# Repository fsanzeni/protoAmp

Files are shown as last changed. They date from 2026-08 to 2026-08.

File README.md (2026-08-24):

# 100W USB-C PD Audio Amplifier with Integrated DSP

This repository contains the hardware design files, documentation, and firmware logic for a 100W audio amplifier board. The system integrates USB-C Power Delivery (PD) for power management, a dedicated digital signal processor (DSP) for audio manipulation, a Bluetooth Low Energy (BLE) microcontroller for system management, and a high-efficiency Class-D amplification stage.

This platform is designed for active speaker systems, custom crossover networks, and integrated audio processing applications requiring a compact footprint and standardised power inputs.

| PCB Front | PCB Back |
|---|---|
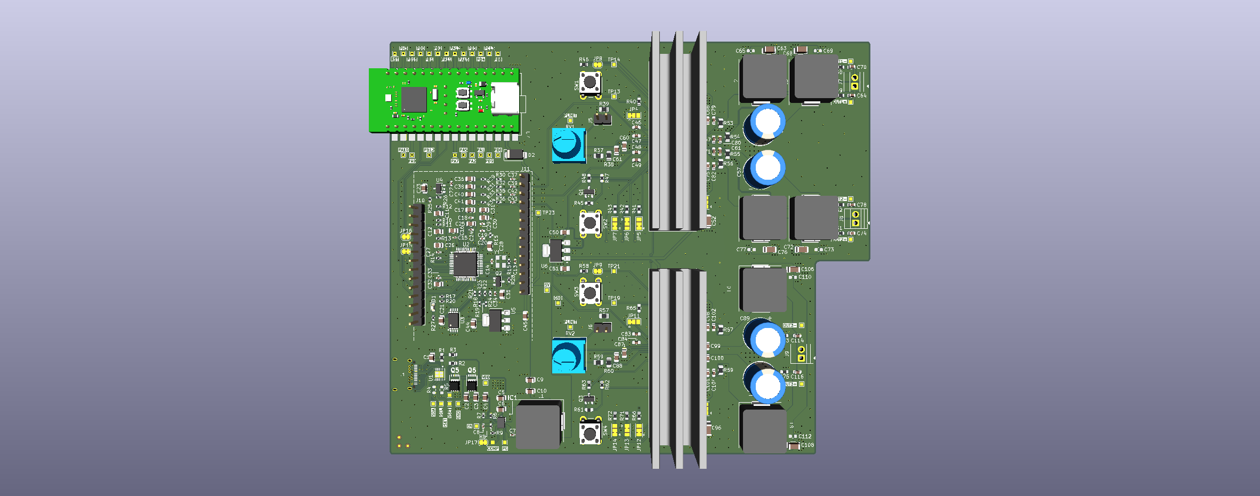
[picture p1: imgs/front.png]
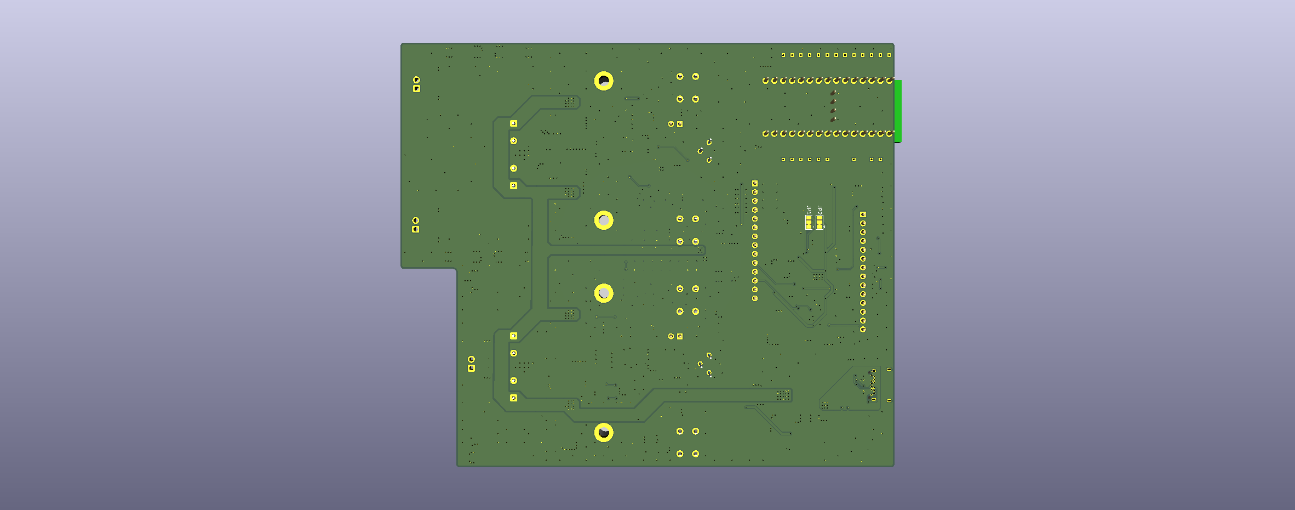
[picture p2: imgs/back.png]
|  |  |

---

## System Architecture and Major Components

The board design relies on a specialised set of integrated circuits to handle power negotiation, wireless connectivity, digital signal processing, and audio amplification.

### USB Power Delivery: HUSB238

The [HUSB238](https://en.hynetek.com/2421.html) serves as the USB Type-C PD sink controller. It handles the low-level negotiation with the connected USB-C power source to request the necessary voltage and current (up to 20V at 5A, yielding 100W).

* **Protocol:** Compliant with USB PD 3.0 and Type-C 1.4 specifications.
* **Interface:** Interfaced via I2C, allowing the system MCU to read negotiated power capabilities and dynamically limit the amplifier's maximum output power to prevent source overcurrent.
* **Functionality:** Operates independently of the MCU for fundamental power requests, ensuring rapid voltage ramp-up and system stability upon cable insertion. Please note: without writing some code and pushing it via the exposed I2C lines, the HUSB238 can only output a maximum of 20V @ 3A (60W). This is a safety feature. Please see e.g., [Adafruit's](https://github.com/adafruit/Adafruit_HUSB238) code to figure out how to request up to 100W.

### Digital Signal Processor: ADAU1701

Audio processing is handled by the Analog Devices [ADAU1701](https://www.analog.com/en/products/adau1701.html), a fully programmable 28-/56-bit audio DSP.

* **Processing:** Executes audio algorithms at a high sample rate, suitable for bi-quad filters, dynamic range compression, time alignment, and active crossovers.
* **I/O Routing:** Features two built-in ADCs and four DACs, allowing for stereo input and up to four channels of analog output (e.g., routing separate high-frequency and low-frequency channels to the amplification stage).
* **Programming:** Configurable via Analog Devices' SigmaStudio. The DSP boots from an external EEPROM or is initialised via the I2C bus by the system MCU.

### System Controller & Wireless: STM32WBA65

The STMicroelectronics [STM32WBA65CIU6](https://www.st.com/en/microcontrollers-microprocessors/stm32wba65ci.html) acts as the central brain of the board. It is an ultra-low-power Arm Cortex-M33 microcontroller with integrated Bluetooth LE Audio capabilities.

* **System Management:** Acts as the I2C master to configure the HUSB238 (via solder jumpers) and the ADAU1701 (loading DSP parameters or switching presets).
* **Connectivity:** Handles Bluetooth Low Energy (BLE) connections for audio streaming and remote configuration, effectively acting as the bridge between mobile applications and the onboard DSP.

### Audio Amplification Stage

The output stage uses a Class-D amplifier topology configured to deliver up to 100W of total output power, distributed as either a bridged mono (PBTL) output or a standard stereo configuration - or a combination of both.

I'm using here a pair of synced [TPA3126D2DADR](https://www.ti.com/product/TPA3126D2/part-details/TPA3126D2DADR) - one configured as a 50-W stereo amp, the second as a 100-W amp. Obviously you can't request their max wattage at the same time, so I've included a PLIMIT circuit for both. You can also limit the individual amp's power limits via the DSP / SigmaStudio, but better safe than sorry!

---

## License

This project is licensed under the MIT License.

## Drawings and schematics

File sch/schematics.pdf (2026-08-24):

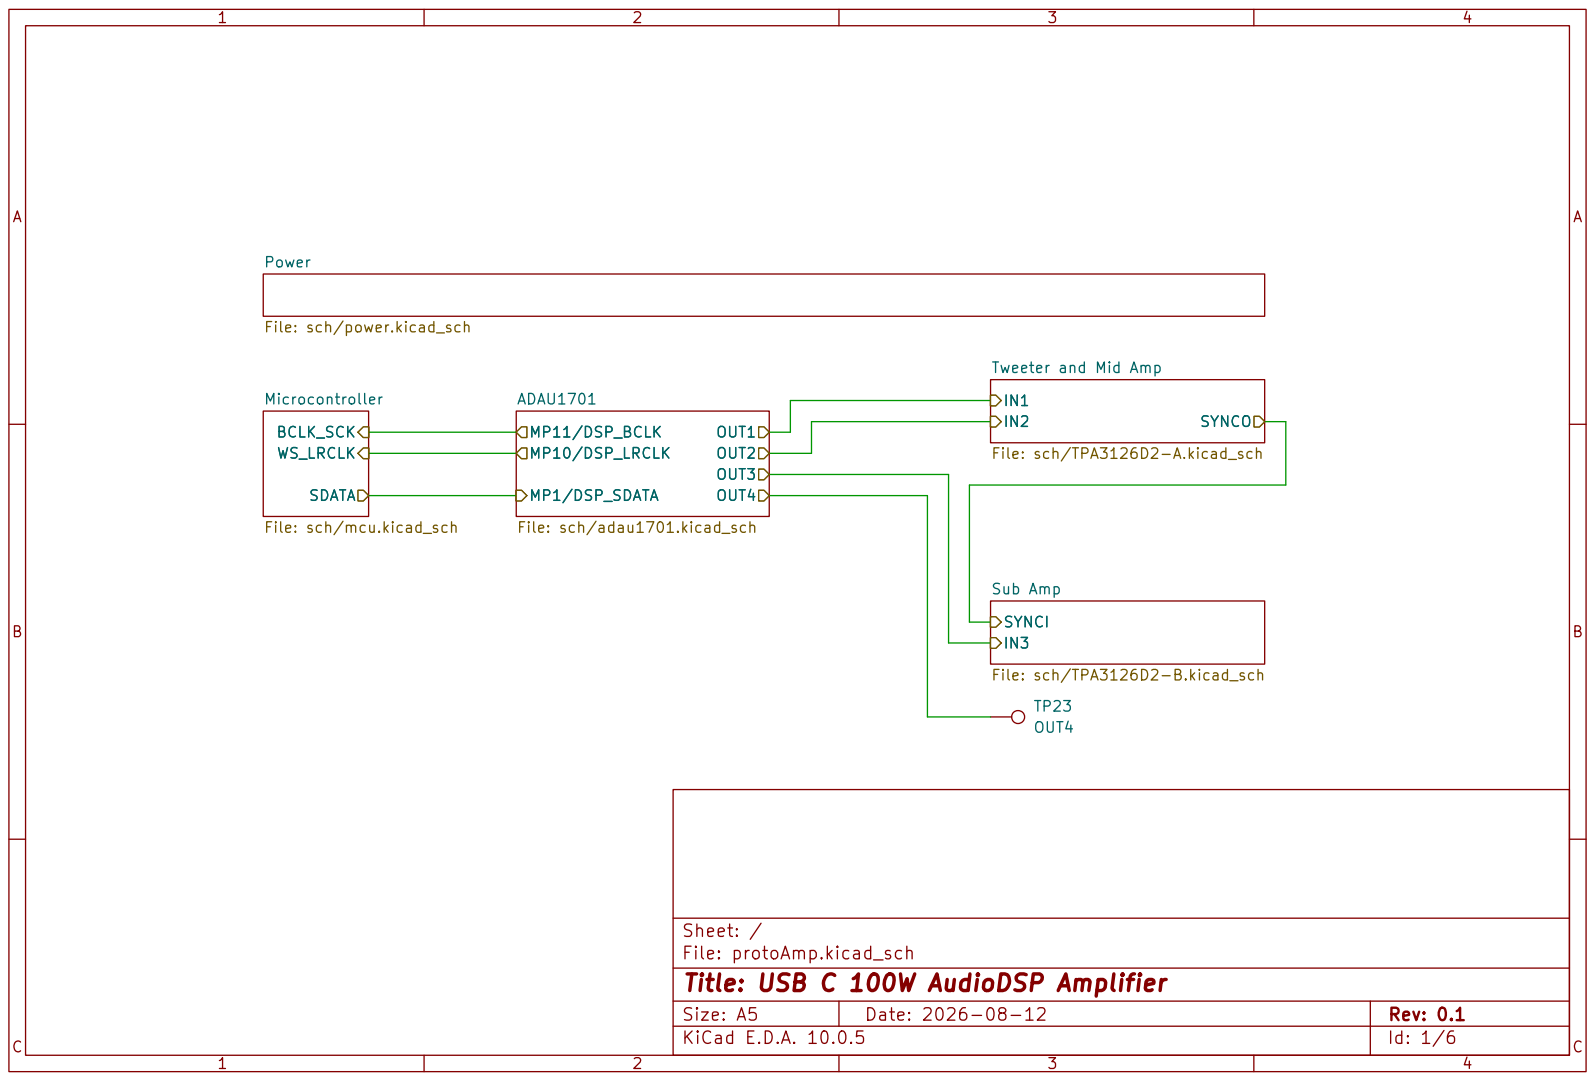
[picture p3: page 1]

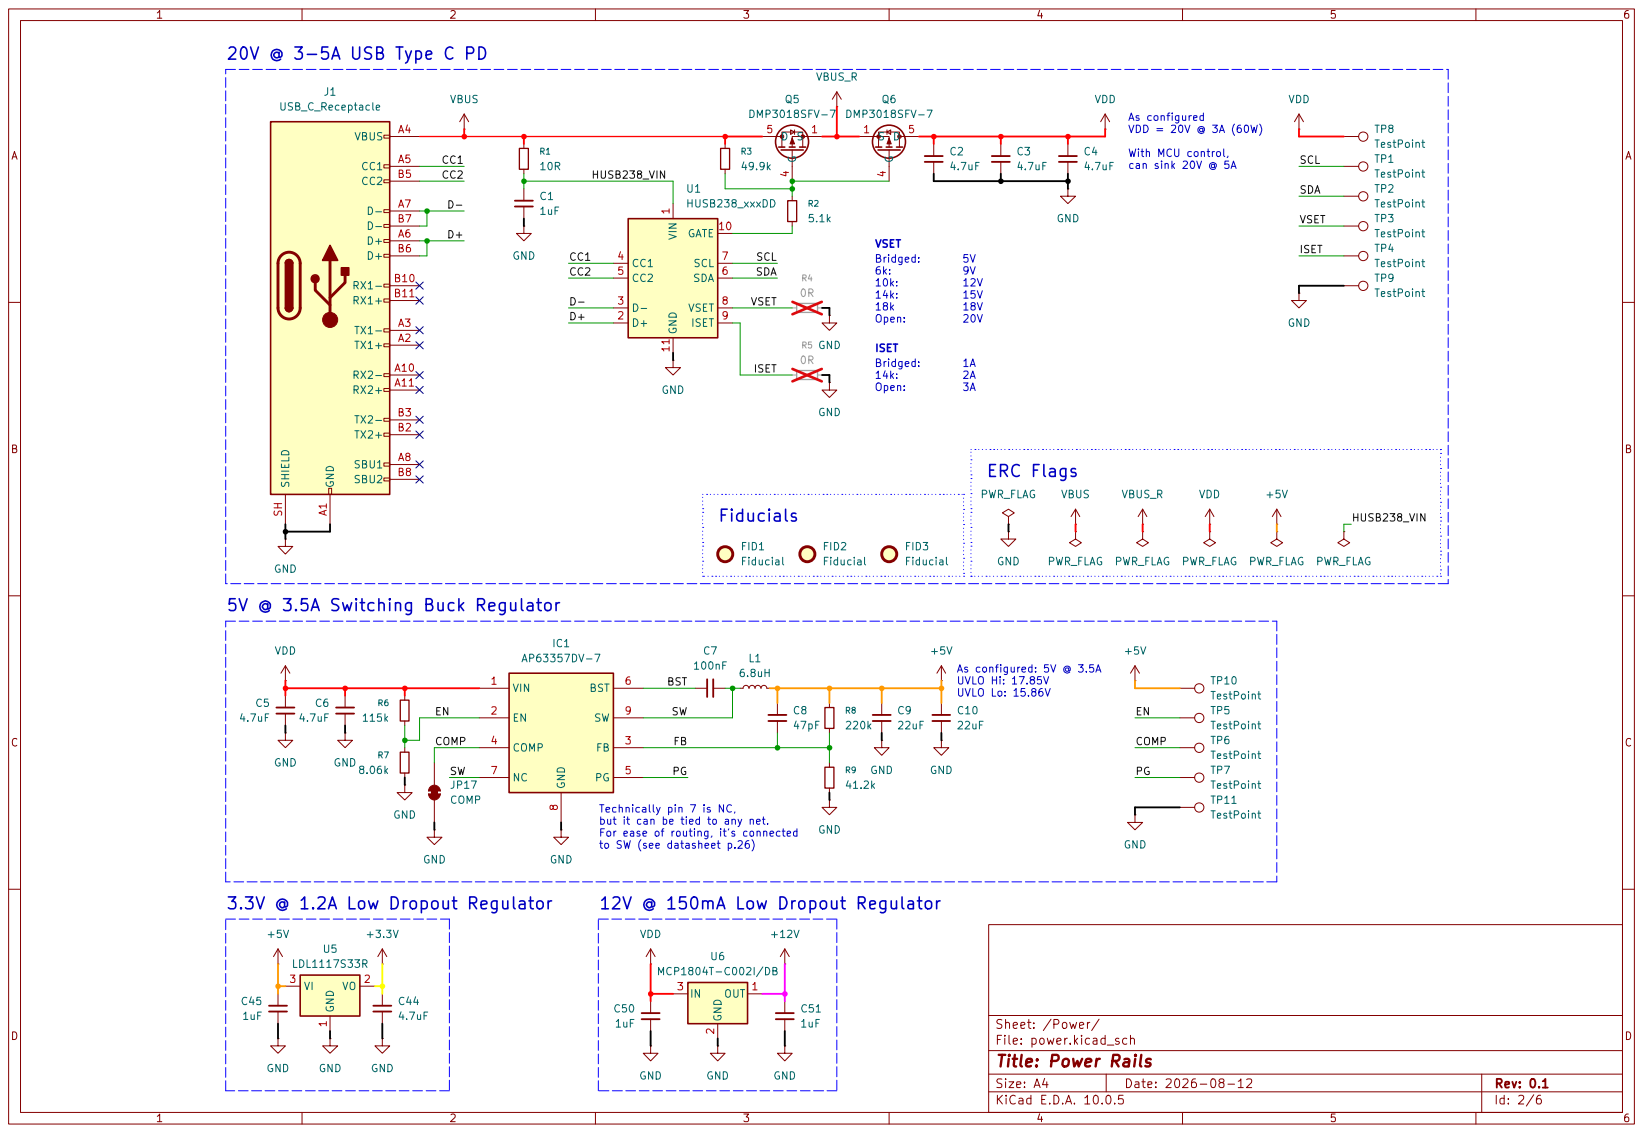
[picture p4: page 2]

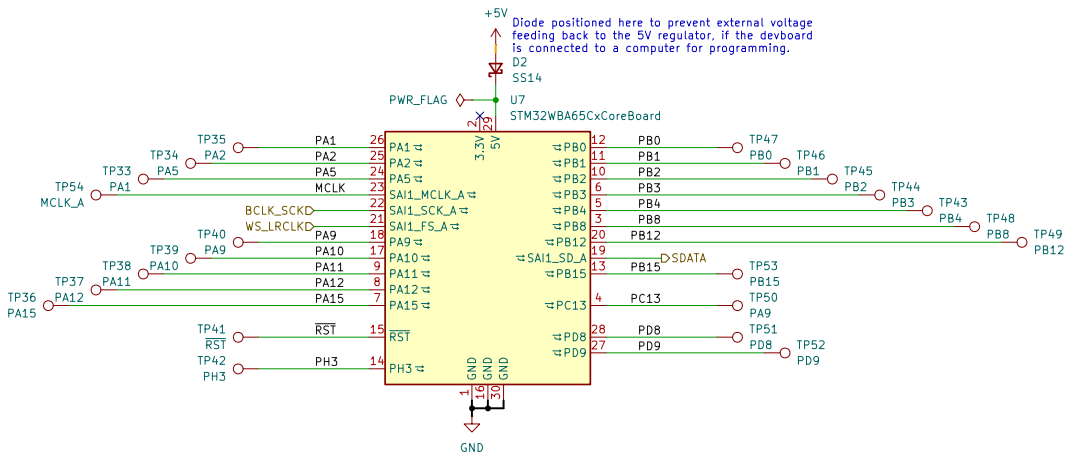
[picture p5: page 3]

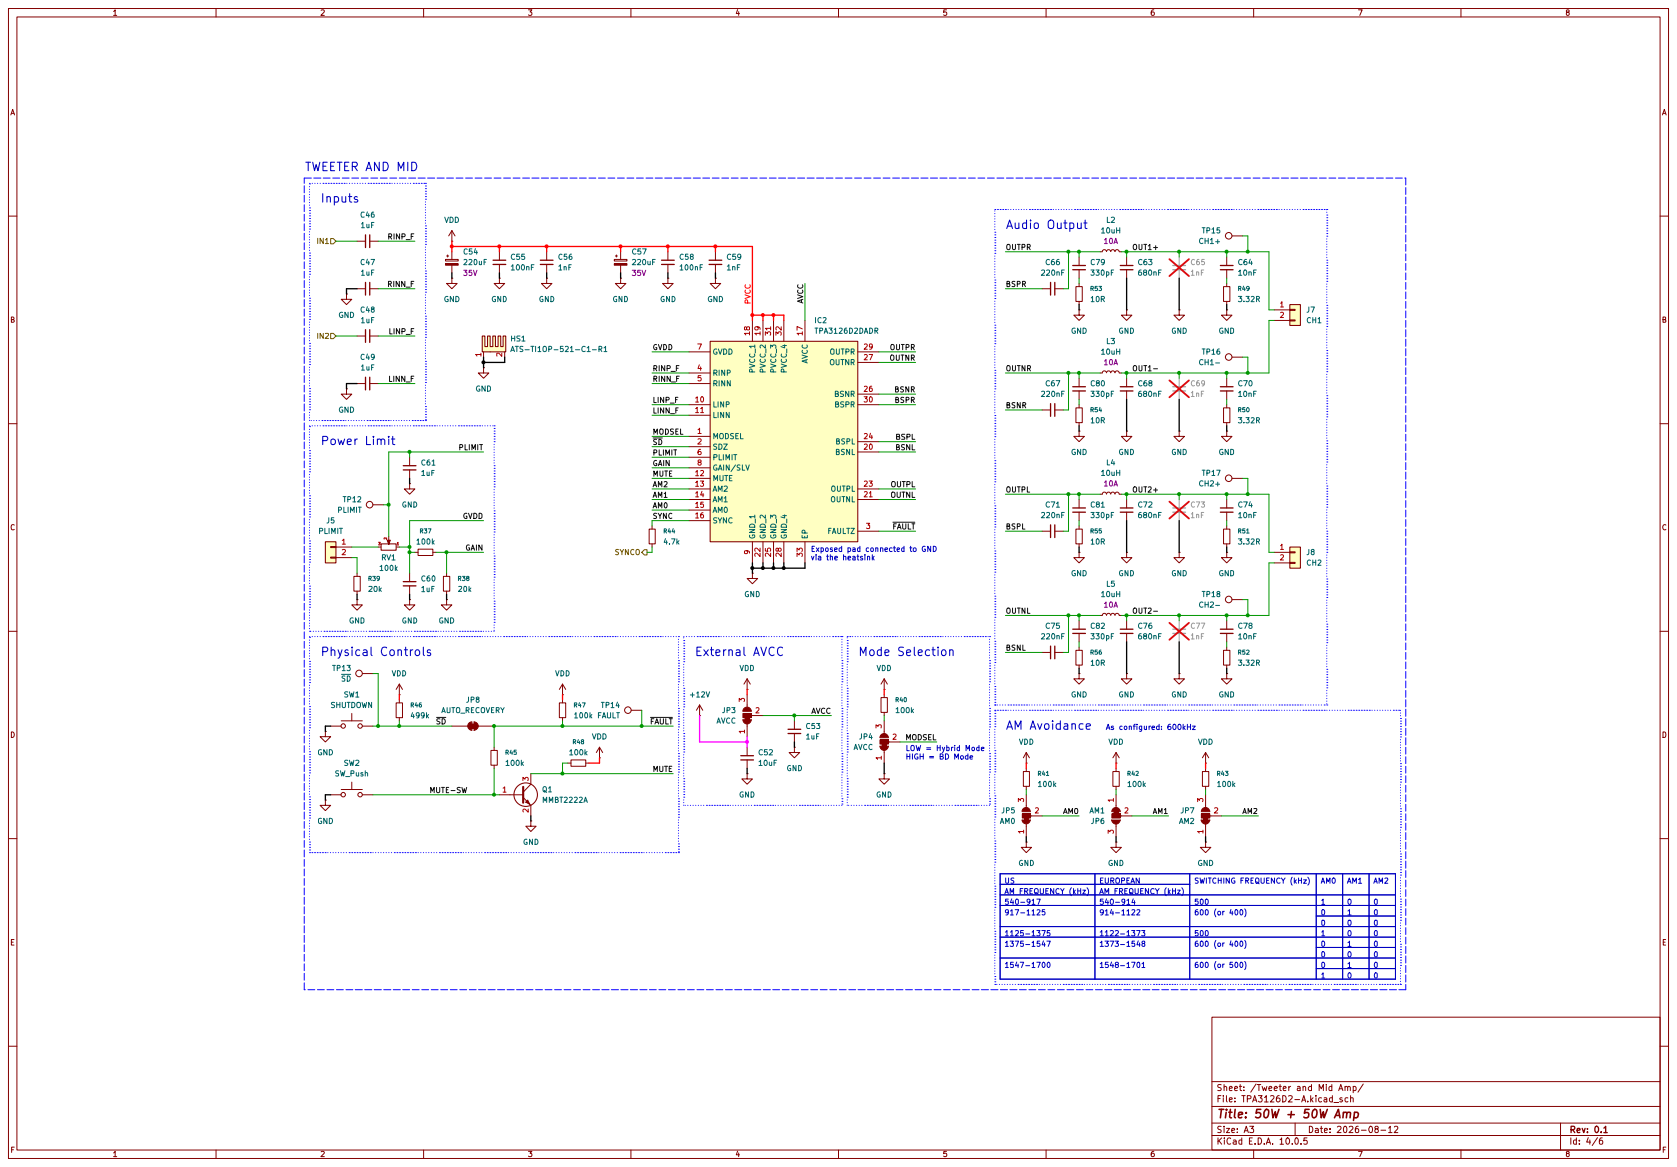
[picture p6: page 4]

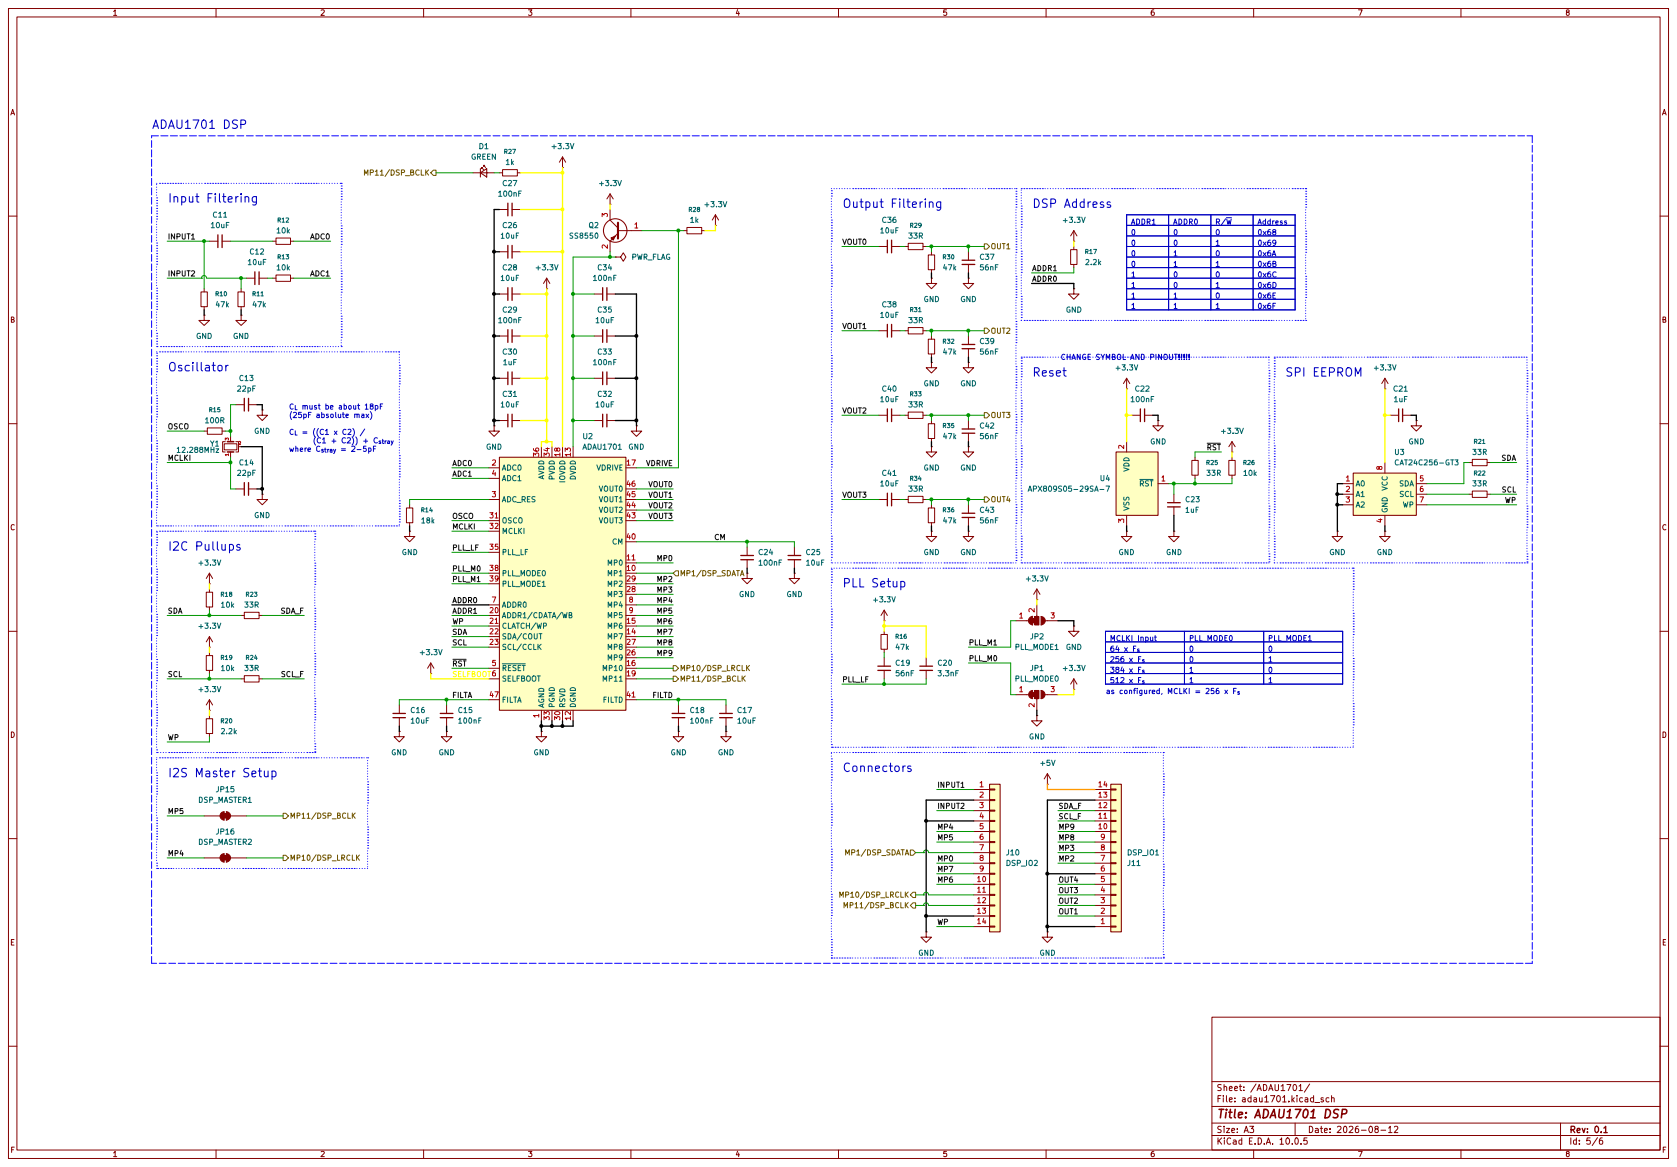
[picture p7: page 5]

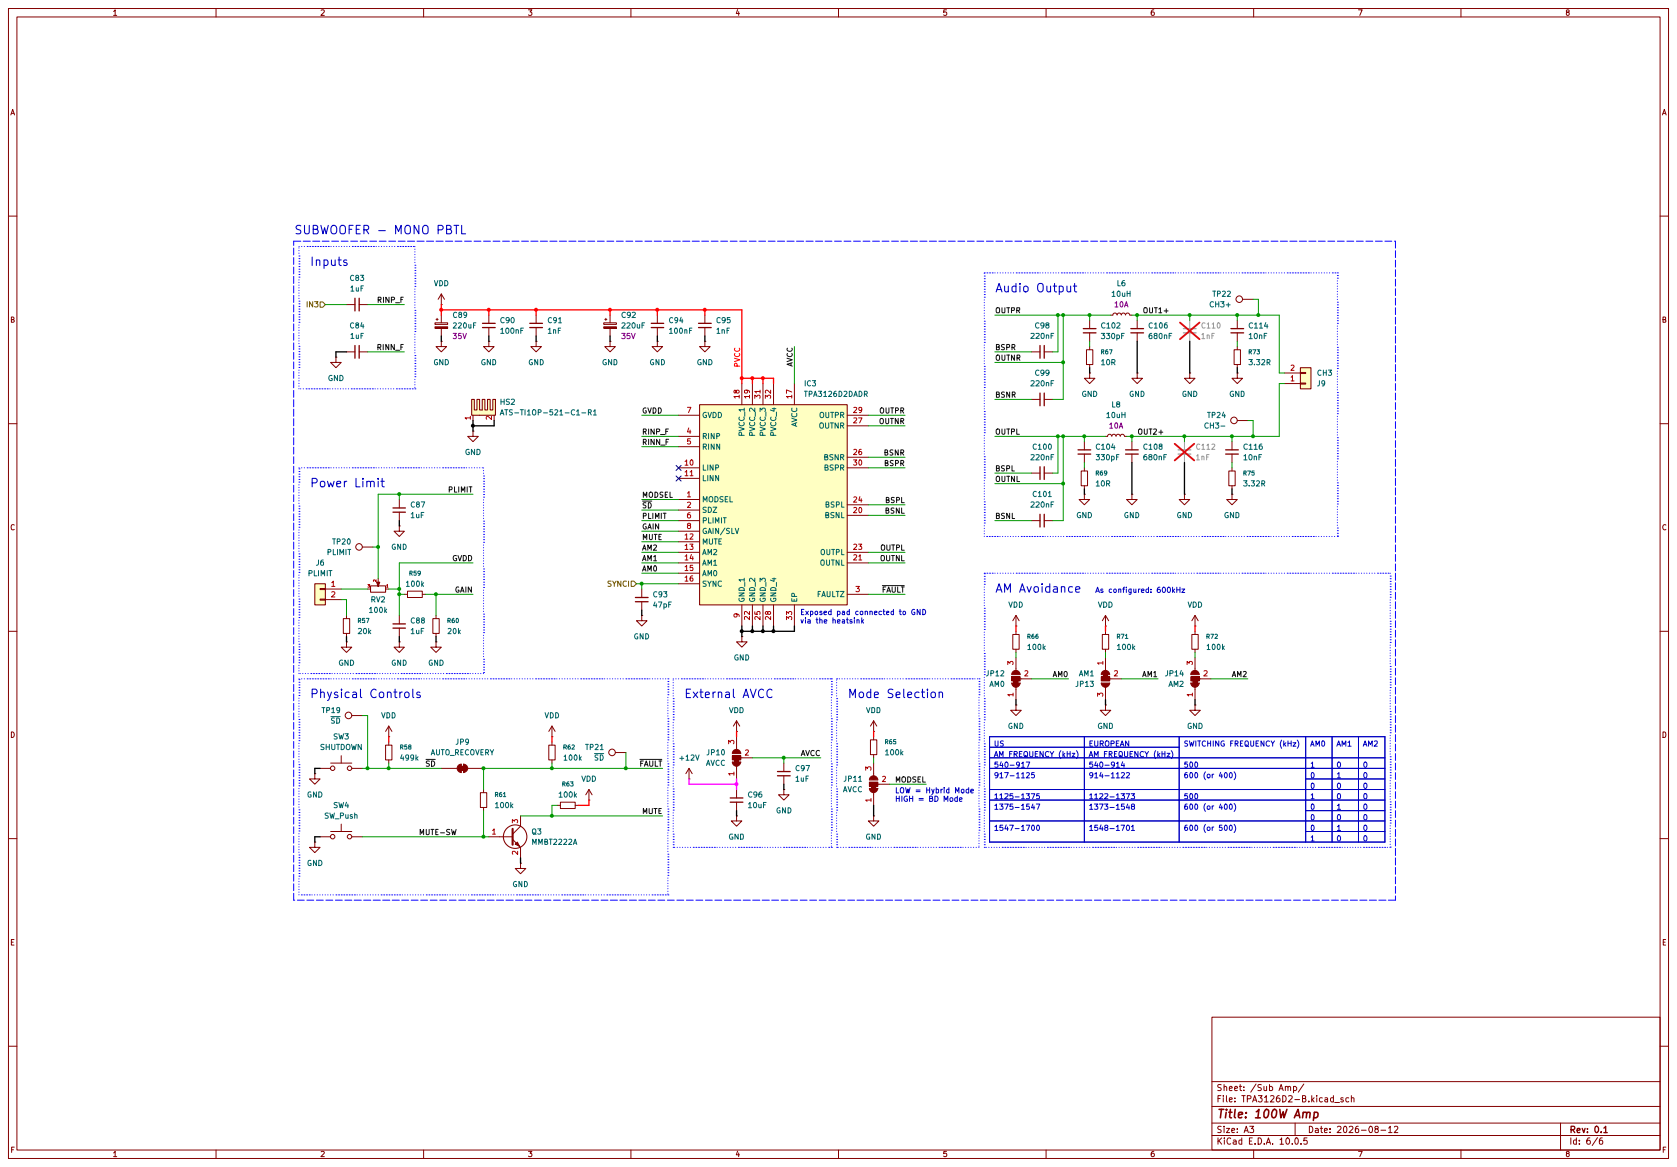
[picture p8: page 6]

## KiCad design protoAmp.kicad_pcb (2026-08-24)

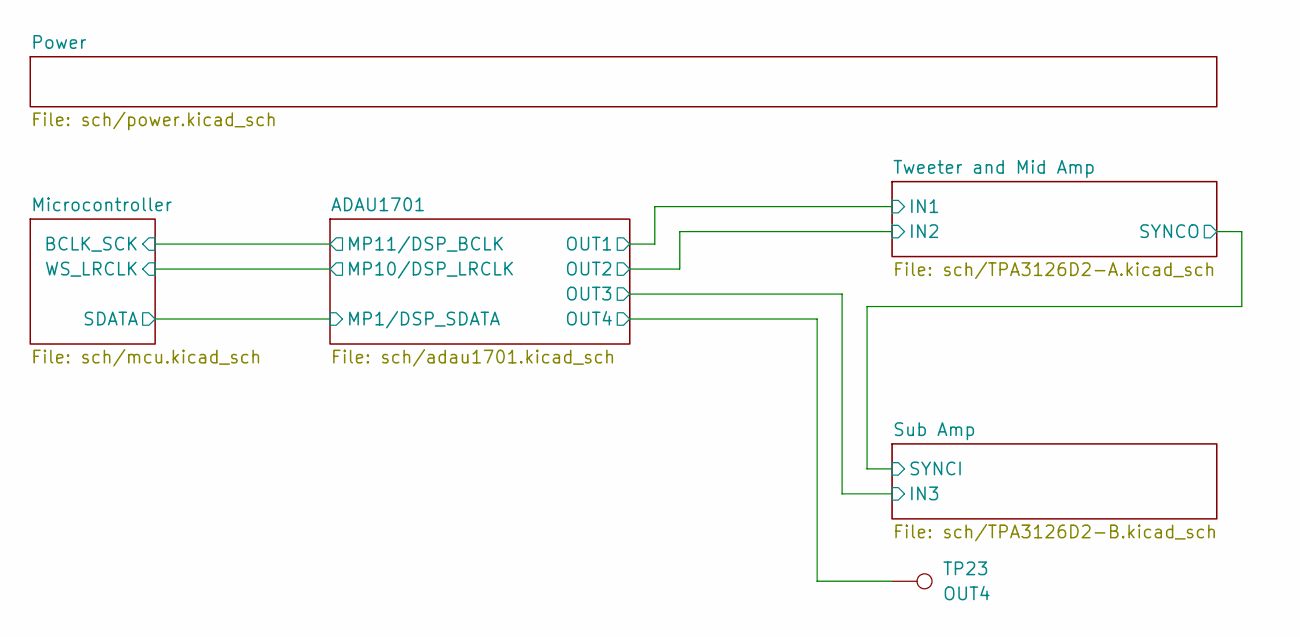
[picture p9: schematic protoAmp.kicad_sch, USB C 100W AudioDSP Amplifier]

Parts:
TP23: OUT4; TestPoint_Pad_1.0x1.0mm

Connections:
/ADAU1701/OUT4: TP23.1 (1_1); also elsewhere on the board

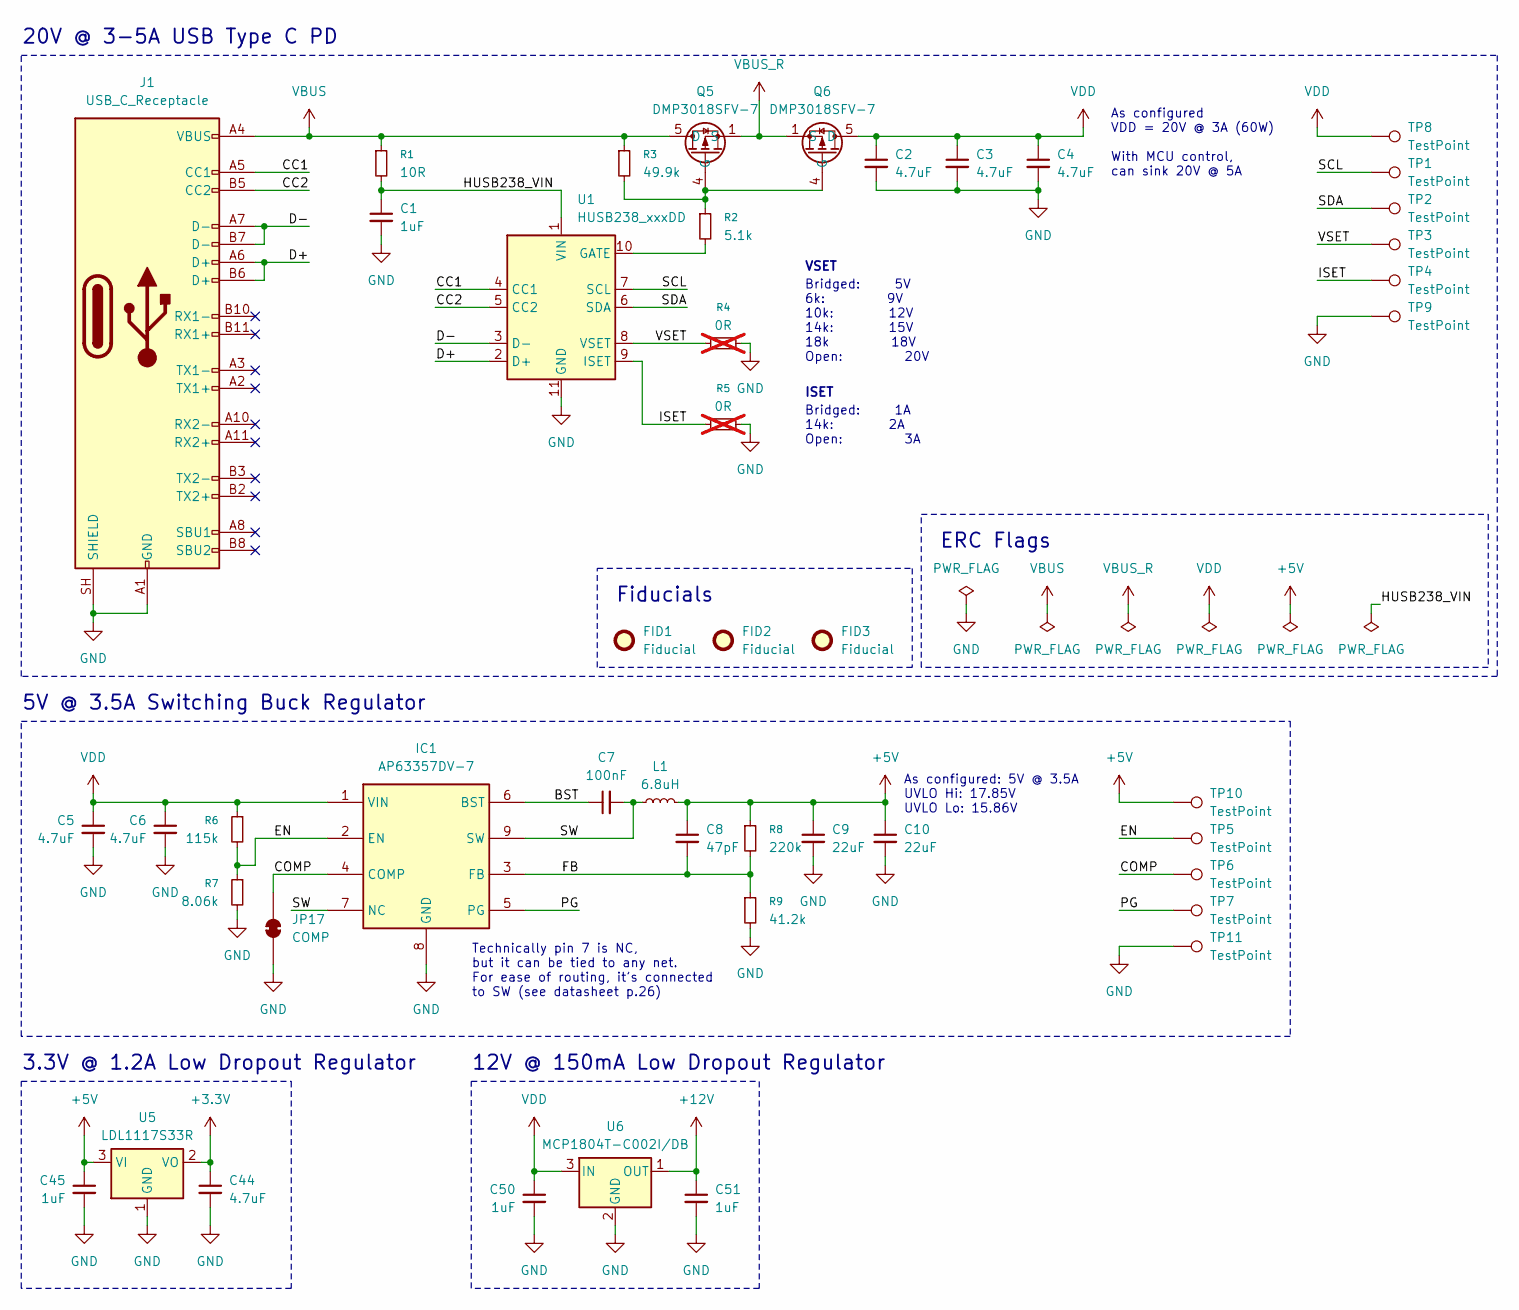
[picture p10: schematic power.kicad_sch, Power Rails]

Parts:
C1, C45, C50, C51: 1uF; C_0805_2012Metric
C2, C3, C4, C5, C6, C44: 4.7uF; C_0805_2012Metric
C7: 100nF; C_0402_1005Metric
C8: 47pF; C_0402_1005Metric
C9, C10: 22uF; C_0805_2012Metric
FID1, FID2, FID3: Fiducial; Fiducial_0.75mm_Mask1.5mm
IC1: AP63357DV-7; AP63357DV7; Mouser Part Number 621-AP63357DV-7
J1: USB_C_Receptacle; USB4900-00-A
JP17: COMP; SolderJumper-2_P1.3mm_Bridged_RoundedPad1.0x1.5mm
L1: 6.8uH; SRP1265A-100M
Q5, Q6: DMP3018SFV-7; DMP3036SFV7; Mouser Part Number 621-DMP3018SFV-7
R1: 10R; R_0603_1608Metric
R2: 5.1k; R_0603_1608Metric
R3: 49.9k; R_0603_1608Metric
R4, R5: 0R; R_0603_1608Metric; not fitted
R6: 115k; R_0402_1005Metric
R7: 8.06k; R_0402_1005Metric
R8: 220k; R_0402_1005Metric
R9: 41.2k; R_0402_1005Metric
TP1, TP2, TP3, TP4, TP5, TP6, TP7, TP8, TP9, TP10, TP11: TestPoint; TestPoint_Pad_1.0x1.0mm
U1: HUSB238_xxxDD; WDFN-10-1EP_3x3mm_P0.5mm_EP1.8x2.5mm
U5: LDL1117S33R; SOT-223-3_TabPin2
U6: MCP1804T-C002I/DB; SOT-223-3_TabPin2

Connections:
+3.3V: C44.1, U5.2 (VO); also elsewhere on the board
+5V: C8.1, C9.1, C10.1, C45.1, L1.2, R8.1, TP10.1 (1_1), U5.3 (VI); also elsewhere on the board
+12V: C51.1, U6.1 (OUT); also elsewhere on the board
/Power/BST: C7.1, IC1.6 (BST)
/Power/CC1: J1.A5 (CC1), U1.4 (CC1)
/Power/CC2: J1.B5 (CC2), U1.5 (CC2)
/Power/COMP: IC1.4 (COMP), JP17.1 (A), TP6.1 (1_1)
/Power/D+: J1.A6 (D+), J1.B6 (D+), U1.2 (D+)
/Power/D-: J1.A7 (D-), J1.B7 (D-), U1.3 (D-)
/Power/EN: IC1.2 (EN), R6.2, R7.1, TP5.1 (1_1)
/Power/FB: C8.2, IC1.3 (FB), R8.2, R9.1
/Power/HUSB238_VIN: C1.1, R1.2, U1.1 (VIN)
/Power/ISET: R5.1, TP4.1 (1_1), U1.9 (ISET)
/Power/PG: IC1.5 (PG), TP7.1 (1_1)
/Power/SCL: TP1.1 (1_1), U1.7 (SCL)
/Power/SDA: TP2.1 (1_1), U1.6 (SDA)
/Power/SW: C7.2, IC1.7 (NC), IC1.9 (SW), L1.1
/Power/VSET: R4.1, TP3.1 (1_1), U1.8 (VSET)
GND: C1.2, C2.2, C3.2, C4.2, C5.2, C6.2, C9.2, C10.2, C44.2, C45.2, C50.2, C51.2, IC1.8 (GND), J1.A1 (GND), J1.A12 (GND), J1.B1 (GND), J1.B12 (GND), J1.SH (SHIELD), JP17.2 (B), R4.2, R5.2, R7.2, R9.2, TP9.1 (1_1), TP11.1 (1_1), U1.11 (GND), U5.1 (GND), U6.2 (GND); also elsewhere on the board
unnamed: Q5.4 (G), Q6.4 (G), R2.1, R3.2
unnamed: R2.2, U1.10 (GATE)
VBUS: J1.A4 (VBUS), J1.A9 (VBUS), J1.B4 (VBUS), J1.B9 (VBUS), Q5.5 (D), Q5.6 (D), Q5.7 (D), Q5.8 (D), Q5.9 (D), R1.1, R3.1
VBUS_R: Q5.1 (S), Q5.2 (S), Q5.3 (S), Q6.1 (S), Q6.2 (S), Q6.3 (S)
VDD: C2.1, C3.1, C4.1, C5.1, C6.1, C50.1, IC1.1 (VIN), Q6.5 (D), Q6.6 (D), Q6.7 (D), Q6.8 (D), Q6.9 (D), R6.1, TP8.1 (1_1), U6.3 (IN); also elsewhere on the board

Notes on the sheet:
3.3V @ 1.2A Low Dropout Regulator
Bridged: 1A 14k: 2A Open: 3A
As configured: 5V @ 3.5A UVLO Hi: 17.85V UVLO Lo: 15.86V
Technically pin 7 is NC, but it can be tied to any net. For ease of routing, it's connected to SW (see datasheet p.26)
20V @ 3-5A USB Type C PD
As configured VDD = 20V @ 3A (60W) With MCU control, can sink 20V @ 5A
Fiducials
5V @ 3.5A Switching Buck Regulator
12V @ 150mA Low Dropout Regulator
VSET
Bridged: 5V 6k: 9V 10k: 12V 14k: 15V 18k 18V Open: 20V
ERC Flags
ISET

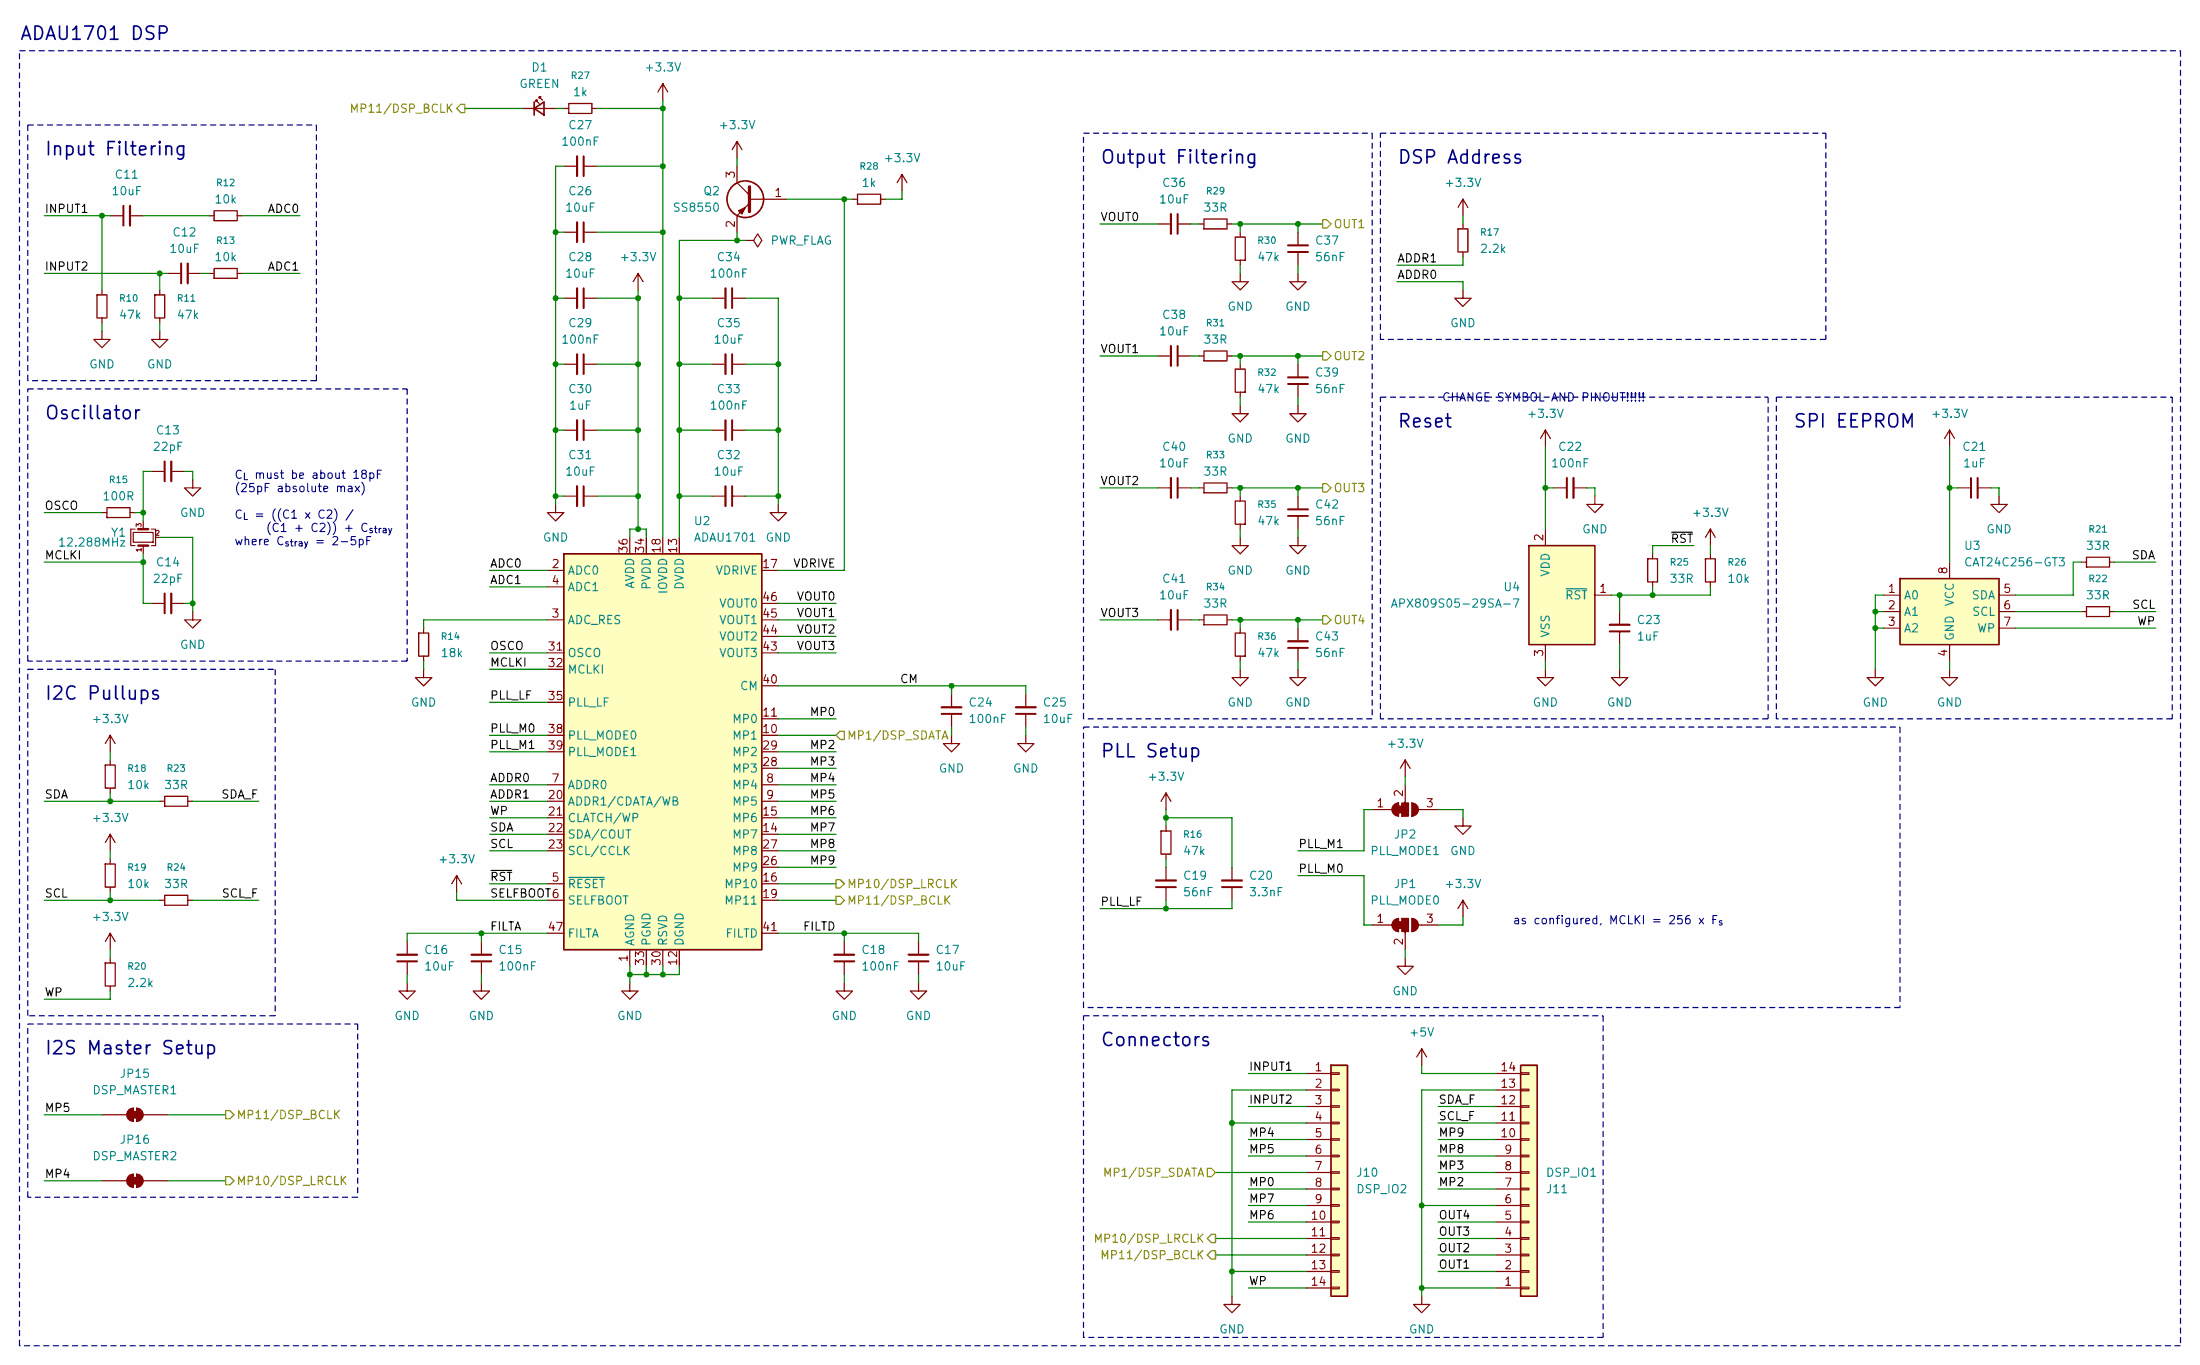
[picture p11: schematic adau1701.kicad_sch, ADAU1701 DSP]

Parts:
C11, C12, C16, C17, C25, C26, C28, C31, C32, C35, C36, C38, C40, C41: 10uF; C_0805_2012Metric
C13, C14: 22pF; C_0402_1005Metric
C15, C18, C22, C24, C27, C29, C33, C34: 100nF; C_0402_1005Metric
C19, C37, C39, C42, C43: 56nF; C_0402_1005Metric
C20: 3.3nF; C_0402_1005Metric
C21, C23, C30: 1uF; C_0805_2012Metric
D1: GREEN; LED_0603_1608Metric
J10: DSP_IO2; PinHeader_1x14_P2.54mm_Vertical
J11: DSP_IO1; PinHeader_1x14_P2.54mm_Vertical
JP1: PLL_MODE0; SolderJumper-3_P1.3mm_Bridged12_Pad1.0x1.5mm
JP2: PLL_MODE1; SolderJumper-3_P1.3mm_Bridged12_Pad1.0x1.5mm
JP15: DSP_MASTER1; SolderJumper-2_P1.3mm_Bridged_RoundedPad1.0x1.5mm
JP16: DSP_MASTER2; SolderJumper-2_P1.3mm_Bridged_RoundedPad1.0x1.5mm
Q2: SS8550; SOT-23
R10, R11, R16, R30, R32, R35, R36: 47k; R_0402_1005Metric
R12, R13, R18, R19, R26: 10k; R_0402_1005Metric
R14: 18k; R_0402_1005Metric
R15: 100R; R_0402_1005Metric
R17, R20: 2.2k; R_0402_1005Metric
R21, R22, R23, R24, R25, R29, R31, R33, R34: 33R; R_0402_1005Metric
R27, R28: 1k; R_0402_1005Metric
U2: ADAU1701; LQFP-48_7x7mm_P0.5mm
U3: CAT24C256-GT3; TSSOP-8_4.4x3mm_P0.65mm
U4: APX809S05-29SA-7; SOT-23-3
Y1: 12.288MHz; XTM32012288JT00351001

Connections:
+3.3V: C20.2, C21.1, C22.1, C26.1, C27.1, C28.1, C29.1, C30.1, C31.1, JP1.3 (B), JP2.2 (C), Q2.3 (C), R16.1, R17.1, R18.1, R19.1, R20.1, R26.1, R27.2, R28.2, U2.6 (SELFBOOT), U2.18 (IOVDD), U2.34 (PVDD), U2.36 (AVDD), U2.48 (AVDD), U3.8 (VCC), U4.2 (VDD); also elsewhere on the board
+5V: J11.14; also elsewhere on the board
/ADAU1701/ADC0: R12.2, U2.2 (ADC0)
/ADAU1701/ADC1: R13.2, U2.4 (ADC1)
/ADAU1701/ADDR1: R17.2, U2.20 (ADDR1/CDATA/WB)
/ADAU1701/CM: C24.2, C25.2, U2.40 (CM)
/ADAU1701/FILTA: C15.2, C16.2, U2.47 (FILTA)
/ADAU1701/FILTD: C17.2, C18.2, U2.41 (FILTD)
/ADAU1701/INPUT1: C11.1, J10.1, R10.1
/ADAU1701/INPUT2: C12.1, J10.3, R11.1
/ADAU1701/MCLKI: C14.1, U2.32 (MCLKI), Y1.1
/ADAU1701/MP0: J10.8, U2.11 (MP0)
/ADAU1701/MP1/DSP_SDATA: J10.7, U2.10 (MP1); also elsewhere on the board
/ADAU1701/MP2: J11.7, U2.29 (MP2)
/ADAU1701/MP3: J11.8, U2.28 (MP3)
/ADAU1701/MP4: J10.5, JP16.2 (B), U2.8 (MP4)
/ADAU1701/MP5: J10.6, JP15.2 (B), U2.9 (MP5)
/ADAU1701/MP6: J10.10, U2.15 (MP6)
/ADAU1701/MP7: J10.9, U2.14 (MP7)
/ADAU1701/MP8: J11.9, U2.27 (MP8)
/ADAU1701/MP9: J11.10, U2.26 (MP9)
/ADAU1701/MP10/DSP_LRCLK: J10.11, JP16.1 (A), U2.16 (MP10); also elsewhere on the board
/ADAU1701/MP11/DSP_BCLK: D1.1 (K), J10.12, JP15.1 (A), U2.19 (MP11); also elsewhere on the board
/ADAU1701/OSCO: R15.1, U2.31 (OSCO)
/ADAU1701/OUT1: C37.2, J11.2, R29.2, R30.2; also elsewhere on the board
/ADAU1701/OUT2: C39.2, J11.3, R31.2, R32.2; also elsewhere on the board
/ADAU1701/OUT3: C42.2, J11.4, R33.2, R35.2; also elsewhere on the board
/ADAU1701/OUT4: C43.2, J11.5, R34.2, R36.2; also elsewhere on the board
/ADAU1701/PLL_LF: C19.1, C20.1, U2.35 (PLL_LF)
/ADAU1701/PLL_M0: JP1.1 (A), U2.38 (PLL_MODE0)
/ADAU1701/PLL_M1: JP2.1 (A), U2.39 (PLL_MODE1)
/ADAU1701/SCL: R19.2, R22.2, R24.1, U2.23 (SCL/CCLK)
/ADAU1701/SCL_F: J11.11, R24.2
/ADAU1701/SDA: R18.2, R21.2, R23.1, U2.22 (SDA/COUT)
/ADAU1701/SDA_F: J11.12, R23.2
/ADAU1701/VDRIVE: Q2.1 (B), R28.1, U2.17 (VDRIVE)
/ADAU1701/VOUT0: C36.2, U2.46 (VOUT0)
/ADAU1701/VOUT1: C38.2, U2.45 (VOUT1)
/ADAU1701/VOUT2: C40.2, U2.44 (VOUT2)
/ADAU1701/VOUT3: C41.2, U2.43 (VOUT3)
/ADAU1701/WP: J10.14, R20.2, U2.21 (CLATCH/WP), U3.7 (WP)
/ADAU1701/~RST: R25.1, U2.5 (~RESET)
GND: C13.2, C14.2, C15.1, C16.1, C17.1, C18.1, C21.2, C22.2, C23.1, C24.1, C25.1, C26.2, C27.2, C28.2, C29.2, C30.2, C31.2, C32.1, C33.1, C34.1, C35.1, C37.1, C39.1, C42.1, C43.1, J10.2, J10.4, J10.13, J11.1, J11.6, J11.13, JP1.2 (C), JP2.3 (B), R10.2, R11.2, R14.2, R30.1, R32.1, R35.1, R36.1, U2.1 (AGND), U2.7 (ADDR0), U2.12 (DGND), U2.25 (DGND), U2.30 (RSVD), U2.33 (PGND), U2.37 (AGND), U2.42 (AGND), U3.1 (A0), U3.2 (A1), U3.3 (A2), U3.4 (GND), U4.3 (VSS), Y1.2 (G), Y1.4 (G); also elsewhere on the board
unnamed: C11.2, R12.1
unnamed: C12.2, R13.1
unnamed: C13.1, R15.2, Y1.3
unnamed: C19.2, R16.2
unnamed: C36.1, R29.1
unnamed: C38.1, R31.1
unnamed: C40.1, R33.1
unnamed: C41.1, R34.1
unnamed: D1.2 (A), R27.1
unnamed: C32.2, C33.2, C34.2, C35.2, Q2.2 (E), U2.13 (DVDD), U2.24 (DVDD)
unnamed: R14.1, U2.3 (ADC_RES)
unnamed: R22.1, U3.6 (SCL)
unnamed: R21.1, U3.5 (SDA)
unnamed: C23.2, R25.2, R26.2, U4.1 (~RST)

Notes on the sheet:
Reset
C_{L} must be about 18pF (25pF absolute max) C_{L} = ((C1 x C2) / (C1 + C2)) + C_{stray} where C_{stray} = 2-5pF
Output Filtering
PLL Setup
ADAU1701 DSP
Input Filtering
I2S Master Setup
SPI EEPROM
Oscillator
I2C Pullups
as configured, MCLKI = 256 x F_{s}
DSP Address
CHANGE SYMBOL AND PINOUT!!!!!
Connectors

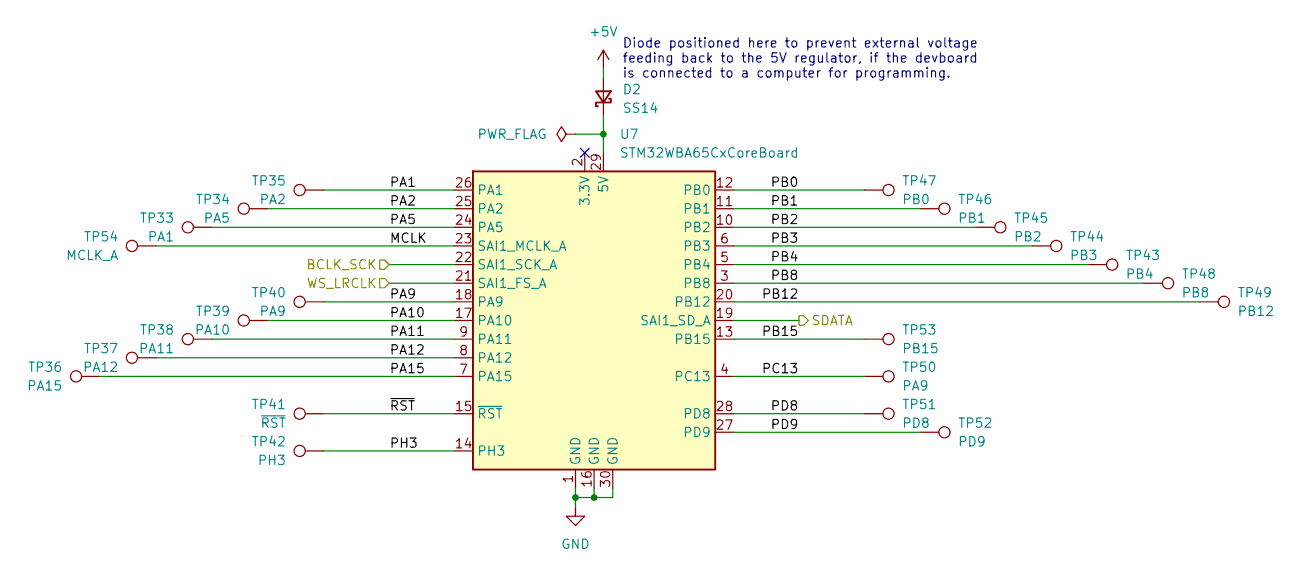
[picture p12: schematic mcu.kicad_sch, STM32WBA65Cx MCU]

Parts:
D2: SS14; D_SMA
TP33: PA1; TestPoint_THTPad_1.0x1.0mm_Drill0.5mm
TP34: PA5; TestPoint_THTPad_1.0x1.0mm_Drill0.5mm
TP35: PA2; TestPoint_THTPad_1.0x1.0mm_Drill0.5mm
TP36: PA15; TestPoint_THTPad_1.0x1.0mm_Drill0.5mm
TP37: PA12; TestPoint_THTPad_1.0x1.0mm_Drill0.5mm
TP38: PA11; TestPoint_THTPad_1.0x1.0mm_Drill0.5mm
TP39: PA10; TestPoint_THTPad_1.0x1.0mm_Drill0.5mm
TP40, TP50: PA9; TestPoint_THTPad_1.0x1.0mm_Drill0.5mm
TP41: ~{RST}; TestPoint_THTPad_1.0x1.0mm_Drill0.5mm
TP42: PH3; TestPoint_THTPad_1.0x1.0mm_Drill0.5mm
TP43: PB4; TestPoint_THTPad_1.0x1.0mm_Drill0.5mm
TP44: PB3; TestPoint_THTPad_1.0x1.0mm_Drill0.5mm
TP45: PB2; TestPoint_THTPad_1.0x1.0mm_Drill0.5mm
TP46: PB1; TestPoint_THTPad_1.0x1.0mm_Drill0.5mm
TP47: PB0; TestPoint_THTPad_1.0x1.0mm_Drill0.5mm
TP48: PB8; TestPoint_THTPad_1.0x1.0mm_Drill0.5mm
TP49: PB12; TestPoint_THTPad_1.0x1.0mm_Drill0.5mm
TP51: PD8; TestPoint_THTPad_1.0x1.0mm_Drill0.5mm
TP52: PD9; TestPoint_THTPad_1.0x1.0mm_Drill0.5mm
TP53: PB15; TestPoint_THTPad_1.0x1.0mm_Drill0.5mm
TP54: MCLK_A; TestPoint_THTPad_1.0x1.0mm_Drill0.5mm
U7: STM32WBA65CxCoreBoard; WeAct STM32WBA65CIU6

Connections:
+5V: D2.2 (A); also elsewhere on the board
/ADAU1701/MP1/DSP_SDATA: U7.19 (SAI1_SD_A); also elsewhere on the board
/ADAU1701/MP10/DSP_LRCLK: U7.21 (SAI1_FS_A); also elsewhere on the board
/ADAU1701/MP11/DSP_BCLK: U7.22 (SAI1_SCK_A); also elsewhere on the board
/Microcontroller/MCLK: TP54.1 (1_1), U7.23 (SAI1_MCLK_A)
/Microcontroller/PA1: TP35.1 (1_1), U7.26 (PA1)
/Microcontroller/PA2: TP34.1 (1_1), U7.25 (PA2)
/Microcontroller/PA5: TP33.1 (1_1), U7.24 (PA5)
/Microcontroller/PA9: TP40.1 (1_1), U7.18 (PA9)
/Microcontroller/PA10: TP39.1 (1_1), U7.17 (PA10)
/Microcontroller/PA11: TP38.1 (1_1), U7.9 (PA11)
/Microcontroller/PA12: TP37.1 (1_1), U7.8 (PA12)
/Microcontroller/PA15: TP36.1 (1_1), U7.7 (PA15)
/Microcontroller/PB0: TP47.1 (1_1), U7.12 (PB0)
/Microcontroller/PB1: TP46.1 (1_1), U7.11 (PB1)
/Microcontroller/PB2: TP45.1 (1_1), U7.10 (PB2)
/Microcontroller/PB3: TP44.1 (1_1), U7.6 (PB3)
/Microcontroller/PB4: TP43.1 (1_1), U7.5 (PB4)
/Microcontroller/PB8: TP48.1 (1_1), U7.3 (PB8)
/Microcontroller/PB12: TP49.1 (1_1), U7.20 (PB12)
/Microcontroller/PB15: TP53.1 (1_1), U7.13 (PB15)
/Microcontroller/PC13: TP50.1 (1_1), U7.4 (PC13)
/Microcontroller/PD8: TP51.1 (1_1), U7.28 (PD8)
/Microcontroller/PD9: TP52.1 (1_1), U7.27 (PD9)
/Microcontroller/PH3: TP42.1 (1_1), U7.14 (PH3)
/Microcontroller/~RST: TP41.1 (1_1), U7.15 (~RST)
GND: U7.1 (GND), U7.16 (GND), U7.30 (GND); also elsewhere on the board
unnamed: D2.1 (K), U7.29 (5V)

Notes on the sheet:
Diode positioned here to prevent external voltage feeding back to the 5V regulator, if the devboard is connected to a computer for programming.

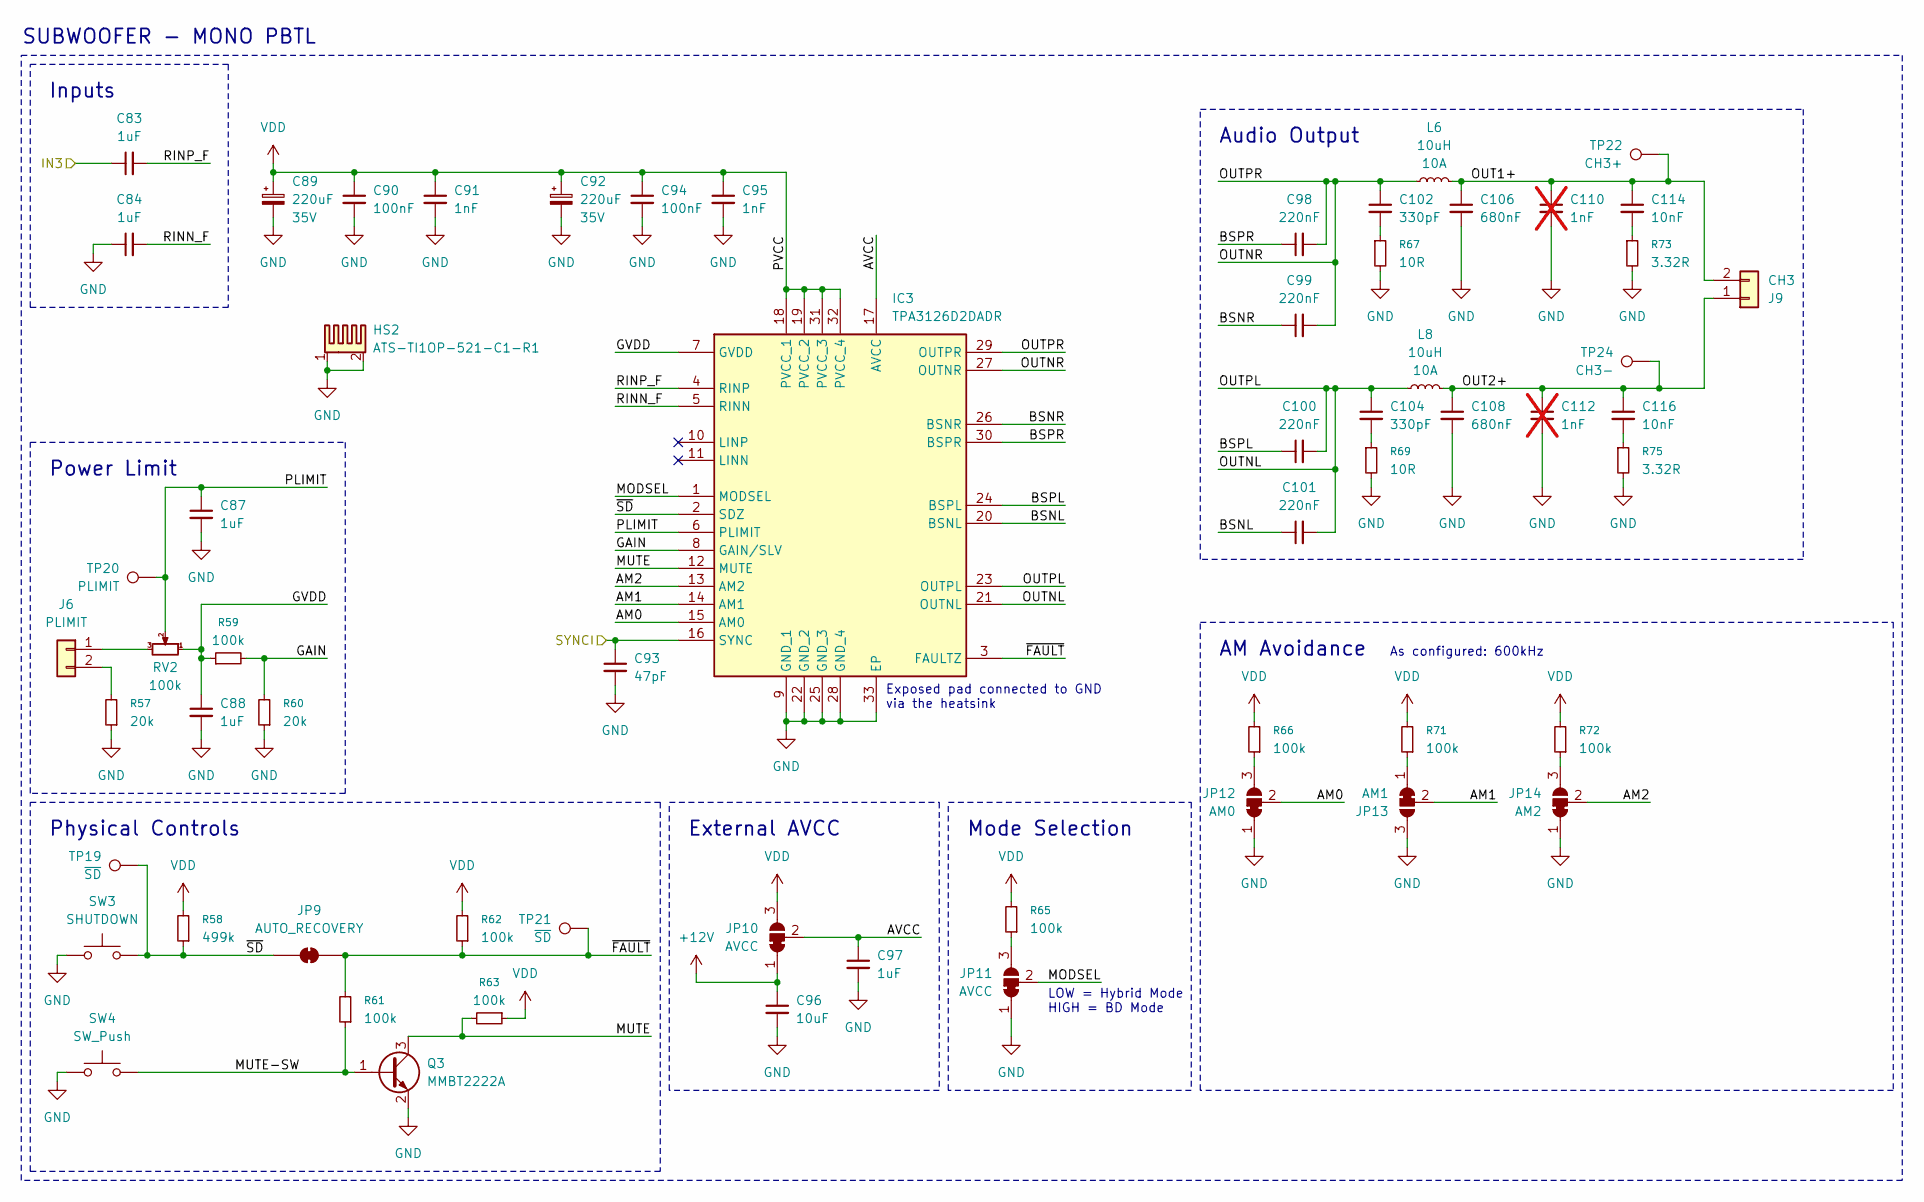
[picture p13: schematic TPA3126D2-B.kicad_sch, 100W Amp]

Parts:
C83, C84, C97: 1uF; C_0603_1608Metric
C87, C88: 1uF; C_0805_2012Metric
C89, C92: 220uF; CP_Radial_D10.0mm_P5.00mm; Rating 35V
C90, C94: 100nF; C_0603_1608Metric
C91, C95: 1nF; C_0603_1608Metric
C93: 47pF; C_0603_1608Metric
C96: 10uF; C_1210_3225Metric
C98, C99, C100, C101: 220nF; C_0603_1608Metric
C102, C104: 330pF; C_0603_1608Metric
C106, C108: 680nF; C_1206_3216Metric
C110, C112: 1nF; C_0603_1608Metric; not fitted
C114, C116: 10nF; C_0603_1608Metric
HS2: ATS-TI1OP-521-C1-R1
IC3: TPA3126D2DADR; SOP65P810X120-33N; Mouser Part Number 595-TPA3126D2DADR
J6: PLIMIT; PinHeader_1x02_P2.54mm_Vertical
J9: CH3; TerminalBlock_Xinya_XY308-2.54-2P_1x02_P2.54mm_Horizontal
JP9: AUTO_RECOVERY; SolderJumper-2_P1.3mm_Bridged_RoundedPad1.0x1.5mm
JP10, JP11: AVCC; SolderJumper-3_P1.3mm_Bridged12_Pad1.0x1.5mm
JP12: AM0; SolderJumper-3_P1.3mm_Bridged12_Pad1.0x1.5mm
JP13: AM1; SolderJumper-3_P1.3mm_Bridged12_Pad1.0x1.5mm
JP14: AM2; SolderJumper-3_P1.3mm_Bridged12_Pad1.0x1.5mm
L6, L8: 10uH; SRP1265A-100M; Rating 10A
Q3: MMBT2222A; SOT-23
R57, R60: 20k; R_0805_2012Metric
R58: 499k; R_0603_1608Metric
R59: 100k; R_0805_2012Metric
R61, R62, R63, R65, R66, R71, R72: 100k; R_0603_1608Metric
R67, R69: 10R; R_0805_2012Metric
R73, R75: 3.32R; R_0603_1608Metric
RV2: 100k; Potentiometer_Bourns_3386P_Vertical
SW3: SHUTDOWN; SW_PUSH_6mm
SW4: SW_Push; SW_PUSH_6mm
TP19, TP21: ~{SD}; TestPoint_Pad_1.0x1.0mm
TP20: PLIMIT; TestPoint_Pad_1.0x1.0mm
TP22: CH3+; TestPoint_Pad_1.0x1.0mm
TP24: CH3-; TestPoint_Pad_1.0x1.0mm

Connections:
+12V: C96.1, JP10.1 (A); also elsewhere on the board
/ADAU1701/OUT3: C83.1; also elsewhere on the board
/Sub Amp/AM0: IC3.15 (AM0), JP12.2 (C)
/Sub Amp/AM1: IC3.14 (AM1), JP13.2 (C)
/Sub Amp/AM2: IC3.13 (AM2), JP14.2 (C)
/Sub Amp/AVCC: C97.1, IC3.17 (AVCC), JP10.2 (C)
/Sub Amp/BSNL: C101.1, IC3.20 (BSNL)
/Sub Amp/BSNR: C99.1, IC3.26 (BSNR)
/Sub Amp/BSPL: C100.1, IC3.24 (BSPL)
/Sub Amp/BSPR: C98.1, IC3.30 (BSPR)
/Sub Amp/GAIN: IC3.8 (GAIN/SLV), R59.2, R60.2
/Sub Amp/GVDD: C88.1, IC3.7 (GVDD), R59.1, RV2.1
/Sub Amp/MODSEL: IC3.1 (MODSEL), JP11.2 (C)
/Sub Amp/MUTE: IC3.12 (MUTE), Q3.3 (C), R63.2
/Sub Amp/MUTE-SW: Q3.1 (B), R61.1, SW4.2
/Sub Amp/OUT1+: C106.1, C110.1, C114.1, J9.2, L6.2, TP22.1 (1_1)
/Sub Amp/OUT2+: C108.1, C112.1, C116.1, J9.1, L8.2, TP24.1 (1_1)
/Sub Amp/OUTNL: C100.2, C101.2, C104.1, IC3.21 (OUTNL), IC3.23 (OUTPL), L8.1
/Sub Amp/OUTNR: C98.2, C99.2, C102.1, IC3.27 (OUTNR), IC3.29 (OUTPR), L6.1
/Sub Amp/PLIMIT: C87.1, IC3.6 (PLIMIT), RV2.2, TP20.1 (1_1)
/Sub Amp/RINN_F: C84.2, IC3.5 (RINN)
/Sub Amp/RINP_F: C83.2, IC3.4 (RINP)
/Sub Amp/SYNCI: C93.1, IC3.16 (SYNC); also elsewhere on the board
/Sub Amp/~FAULT: IC3.3 (FAULTZ), JP9.2 (B), R61.2, R62.1, TP21.1 (1_1)
/Sub Amp/~SD: IC3.2 (SDZ), JP9.1 (A), R58.1, SW3.2, TP19.1 (1_1)
GND: C84.1, C87.2, C88.2, C89.2, C90.2, C91.2, C92.2, C93.2, C94.2, C95.2, C96.2, C97.2, C106.2, C108.2, C110.2, C112.2, HS2.1, HS2.2, IC3.9 (GND_1), IC3.22 (GND_2), IC3.25 (GND_3), IC3.28 (GND_4), IC3.33 (EP), JP11.1 (A), JP12.1 (A), JP13.3 (B), JP14.1 (A), Q3.2 (E), R57.1, R60.1, R67.2, R69.2, R73.2, R75.2, SW3.1, SW4.1; also elsewhere on the board
unnamed: C102.2, R67.1
unnamed: C104.2, R69.1
unnamed: C114.2, R73.1
unnamed: C116.2, R75.1
unnamed: J6.1, RV2.3
unnamed: J6.2, R57.2
unnamed: JP11.3 (B), R65.1
unnamed: JP12.3 (B), R66.1
unnamed: JP13.1 (A), R71.1
unnamed: JP14.3 (B), R72.1
VDD: C89.1, C90.1, C91.1, C92.1, C94.1, C95.1, IC3.18 (PVCC_1), IC3.19 (PVCC_2), IC3.31 (PVCC_3), IC3.32 (PVCC_4), JP10.3 (B), R58.2, R62.2, R63.1, R65.2, R66.2, R71.2, R72.2; also elsewhere on the board

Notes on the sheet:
Audio Output
External AVCC
SUBWOOFER - MONO PBTL
Power Limit
As configured: 600kHz
Inputs
Physical Controls
LOW = Hybrid Mode HIGH = BD Mode
AM Avoidance
Exposed pad connected to GND via the heatsink
Mode Selection

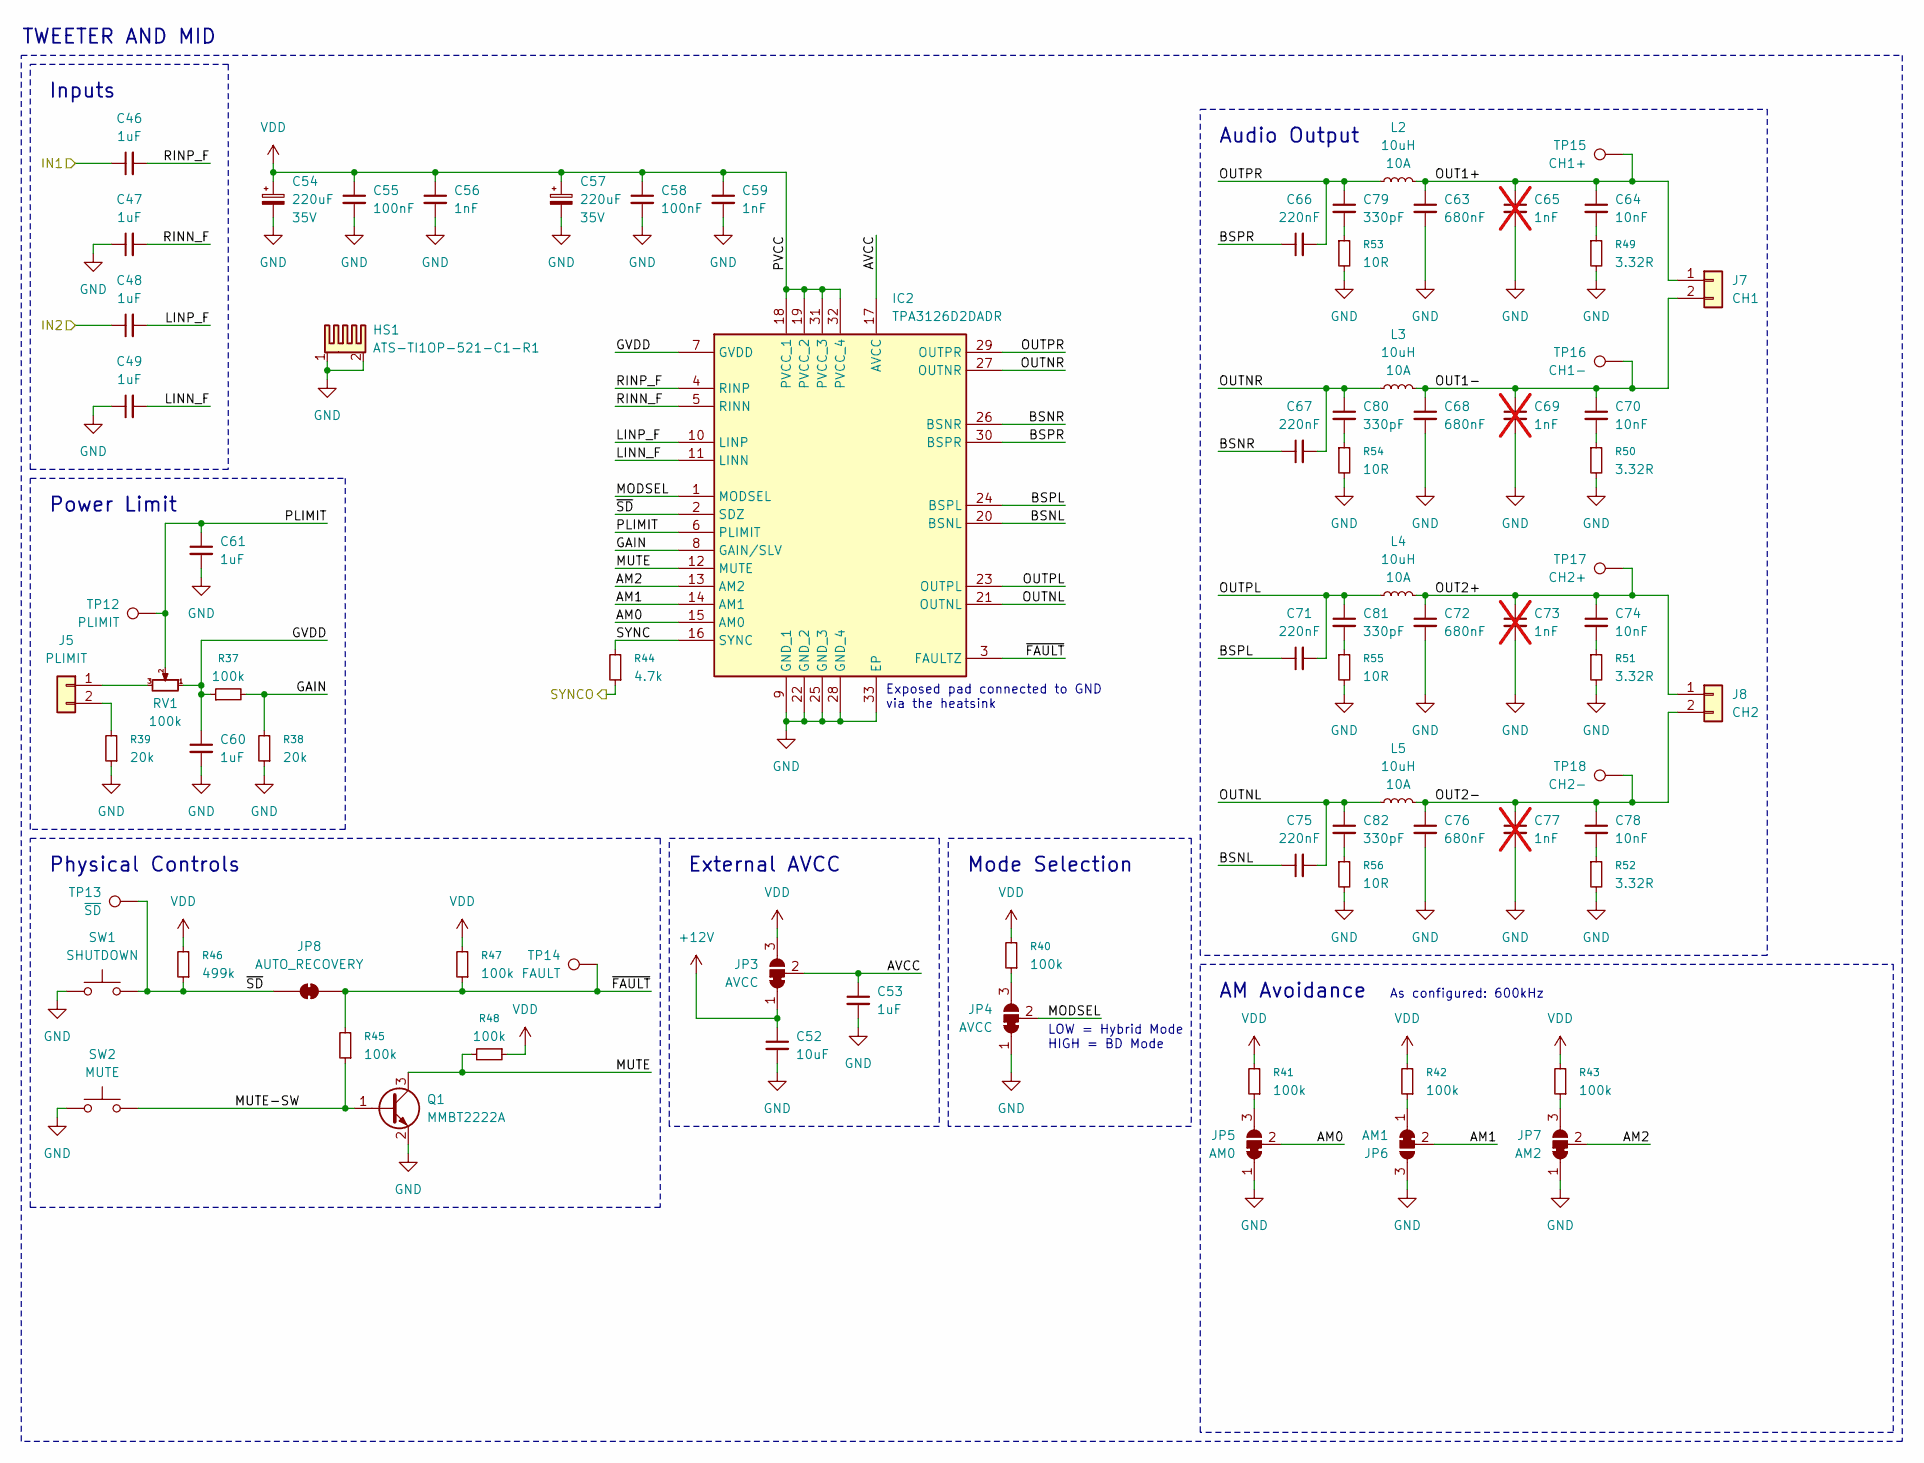
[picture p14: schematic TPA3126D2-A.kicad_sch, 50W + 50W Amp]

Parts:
C46, C47, C48, C49, C53: 1uF; C_0603_1608Metric
C52: 10uF; C_1210_3225Metric
C54, C57: 220uF; CP_Radial_D10.0mm_P5.00mm; Rating 35V
C55, C58: 100nF; C_0603_1608Metric
C56, C59: 1nF; C_0603_1608Metric
C60, C61: 1uF; C_0805_2012Metric
C63, C68, C72, C76: 680nF; C_1206_3216Metric
C64, C70, C74, C78: 10nF; C_0603_1608Metric
C65, C69, C73, C77: 1nF; C_0603_1608Metric; not fitted
C66, C67, C71, C75: 220nF; C_0603_1608Metric
C79, C80, C81, C82: 330pF; C_0603_1608Metric
HS1: ATS-TI1OP-521-C1-R1
IC2: TPA3126D2DADR; SOP65P810X120-33N; Mouser Part Number 595-TPA3126D2DADR
J5: PLIMIT; PinHeader_1x02_P2.54mm_Vertical
J7: CH1; TerminalBlock_Xinya_XY308-2.54-2P_1x02_P2.54mm_Horizontal
J8: CH2; TerminalBlock_Xinya_XY308-2.54-2P_1x02_P2.54mm_Horizontal
JP3, JP4: AVCC; SolderJumper-3_P1.3mm_Bridged12_Pad1.0x1.5mm
JP5: AM0; SolderJumper-3_P1.3mm_Bridged12_Pad1.0x1.5mm
JP6: AM1; SolderJumper-3_P1.3mm_Bridged12_Pad1.0x1.5mm
JP7: AM2; SolderJumper-3_P1.3mm_Bridged12_Pad1.0x1.5mm
JP8: AUTO_RECOVERY; SolderJumper-2_P1.3mm_Bridged_RoundedPad1.0x1.5mm
L2, L3, L4, L5: 10uH; SRP1265A-100M; Rating 10A
Q1: MMBT2222A; SOT-23
R37: 100k; R_0805_2012Metric
R38, R39: 20k; R_0805_2012Metric
R40, R41, R42, R43, R45, R47, R48: 100k; R_0603_1608Metric
R44: 4.7k; R_0603_1608Metric
R46: 499k; R_0603_1608Metric
R49, R50, R51, R52: 3.32R; R_0603_1608Metric
R53, R54, R55, R56: 10R; R_0805_2012Metric
RV1: 100k; Potentiometer_Bourns_3386P_Vertical
SW1: SHUTDOWN; SW_PUSH_6mm
SW2: MUTE; SW_PUSH_6mm
TP12: PLIMIT; TestPoint_Pad_1.0x1.0mm
TP13: ~{SD}; TestPoint_Pad_1.0x1.0mm
TP14: FAULT; TestPoint_Pad_1.0x1.0mm
TP15: CH1+; TestPoint_Pad_1.0x1.0mm
TP16: CH1-; TestPoint_Pad_1.0x1.0mm
TP17: CH2+; TestPoint_Pad_1.0x1.0mm
TP18: CH2-; TestPoint_Pad_1.0x1.0mm

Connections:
+12V: C52.1, JP3.1 (A); also elsewhere on the board
/ADAU1701/OUT1: C46.1; also elsewhere on the board
/ADAU1701/OUT2: C48.1; also elsewhere on the board
/Sub Amp/SYNCI: R44.1; also elsewhere on the board
/Tweeter and Mid Amp/AM0: IC2.15 (AM0), JP5.2 (C)
/Tweeter and Mid Amp/AM1: IC2.14 (AM1), JP6.2 (C)
/Tweeter and Mid Amp/AM2: IC2.13 (AM2), JP7.2 (C)
/Tweeter and Mid Amp/AVCC: C53.1, IC2.17 (AVCC), JP3.2 (C)
/Tweeter and Mid Amp/BSNL: C75.1, IC2.20 (BSNL)
/Tweeter and Mid Amp/BSNR: C67.1, IC2.26 (BSNR)
/Tweeter and Mid Amp/BSPL: C71.1, IC2.24 (BSPL)
/Tweeter and Mid Amp/BSPR: C66.1, IC2.30 (BSPR)
/Tweeter and Mid Amp/GAIN: IC2.8 (GAIN/SLV), R37.2, R38.2
/Tweeter and Mid Amp/GVDD: C60.1, IC2.7 (GVDD), R37.1, RV1.1
/Tweeter and Mid Amp/LINN_F: C49.2, IC2.11 (LINN)
/Tweeter and Mid Amp/LINP_F: C48.2, IC2.10 (LINP)
/Tweeter and Mid Amp/MODSEL: IC2.1 (MODSEL), JP4.2 (C)
/Tweeter and Mid Amp/MUTE: IC2.12 (MUTE), Q1.3 (C), R48.2
/Tweeter and Mid Amp/MUTE-SW: Q1.1 (B), R45.1, SW2.2
/Tweeter and Mid Amp/OUT1+: C63.1, C64.1, C65.1, J7.1, L2.2, TP15.1 (1_1)
/Tweeter and Mid Amp/OUT1-: C68.1, C69.1, C70.1, J7.2, L3.2, TP16.1 (1_1)
/Tweeter and Mid Amp/OUT2+: C72.1, C73.1, C74.1, J8.1, L4.2, TP17.1 (1_1)
/Tweeter and Mid Amp/OUT2-: C76.1, C77.1, C78.1, J8.2, L5.2, TP18.1 (1_1)
/Tweeter and Mid Amp/OUTNL: C75.2, C82.1, IC2.21 (OUTNL), L5.1
/Tweeter and Mid Amp/OUTNR: C67.2, C80.1, IC2.27 (OUTNR), L3.1
/Tweeter and Mid Amp/OUTPL: C71.2, C81.1, IC2.23 (OUTPL), L4.1
/Tweeter and Mid Amp/OUTPR: C66.2, C79.1, IC2.29 (OUTPR), L2.1
/Tweeter and Mid Amp/PLIMIT: C61.1, IC2.6 (PLIMIT), RV1.2, TP12.1 (1_1)
/Tweeter and Mid Amp/RINN_F: C47.2, IC2.5 (RINN)
/Tweeter and Mid Amp/RINP_F: C46.2, IC2.4 (RINP)
/Tweeter and Mid Amp/SYNC: IC2.16 (SYNC), R44.2
/Tweeter and Mid Amp/~FAULT: IC2.3 (FAULTZ), JP8.2 (B), R45.2, R47.1, TP14.1 (1_1)
/Tweeter and Mid Amp/~SD: IC2.2 (SDZ), JP8.1 (A), R46.1, SW1.2, TP13.1 (1_1)
GND: C47.1, C49.1, C52.2, C53.2, C54.2, C55.2, C56.2, C57.2, C58.2, C59.2, C60.2, C61.2, C63.2, C65.2, C68.2, C69.2, C72.2, C73.2, C76.2, C77.2, HS1.1, HS1.2, IC2.9 (GND_1), IC2.22 (GND_2), IC2.25 (GND_3), IC2.28 (GND_4), IC2.33 (EP), JP4.1 (A), JP5.1 (A), JP6.3 (B), JP7.1 (A), Q1.2 (E), R38.1, R39.1, R49.2, R50.2, R51.2, R52.2, R53.2, R54.2, R55.2, R56.2, SW1.1, SW2.1; also elsewhere on the board
unnamed: C64.2, R49.1
unnamed: C70.2, R50.1
unnamed: C74.2, R51.1
unnamed: C78.2, R52.1
unnamed: C79.2, R53.1
unnamed: C80.2, R54.1
unnamed: C81.2, R55.1
unnamed: C82.2, R56.1
unnamed: J5.1, RV1.3
unnamed: J5.2, R39.2
unnamed: JP4.3 (B), R40.1
unnamed: JP5.3 (B), R41.1
unnamed: JP6.1 (A), R42.1
unnamed: JP7.3 (B), R43.1
VDD: C54.1, C55.1, C56.1, C57.1, C58.1, C59.1, IC2.18 (PVCC_1), IC2.19 (PVCC_2), IC2.31 (PVCC_3), IC2.32 (PVCC_4), JP3.3 (B), R40.2, R41.2, R42.2, R43.2, R46.2, R47.2, R48.1; also elsewhere on the board

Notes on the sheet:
Exposed pad connected to GND via the heatsink
External AVCC
Physical Controls
As configured: 600kHz
Mode Selection
Audio Output
TWEETER AND MID
Power Limit
Inputs
AM Avoidance
LOW = Hybrid Mode HIGH = BD Mode

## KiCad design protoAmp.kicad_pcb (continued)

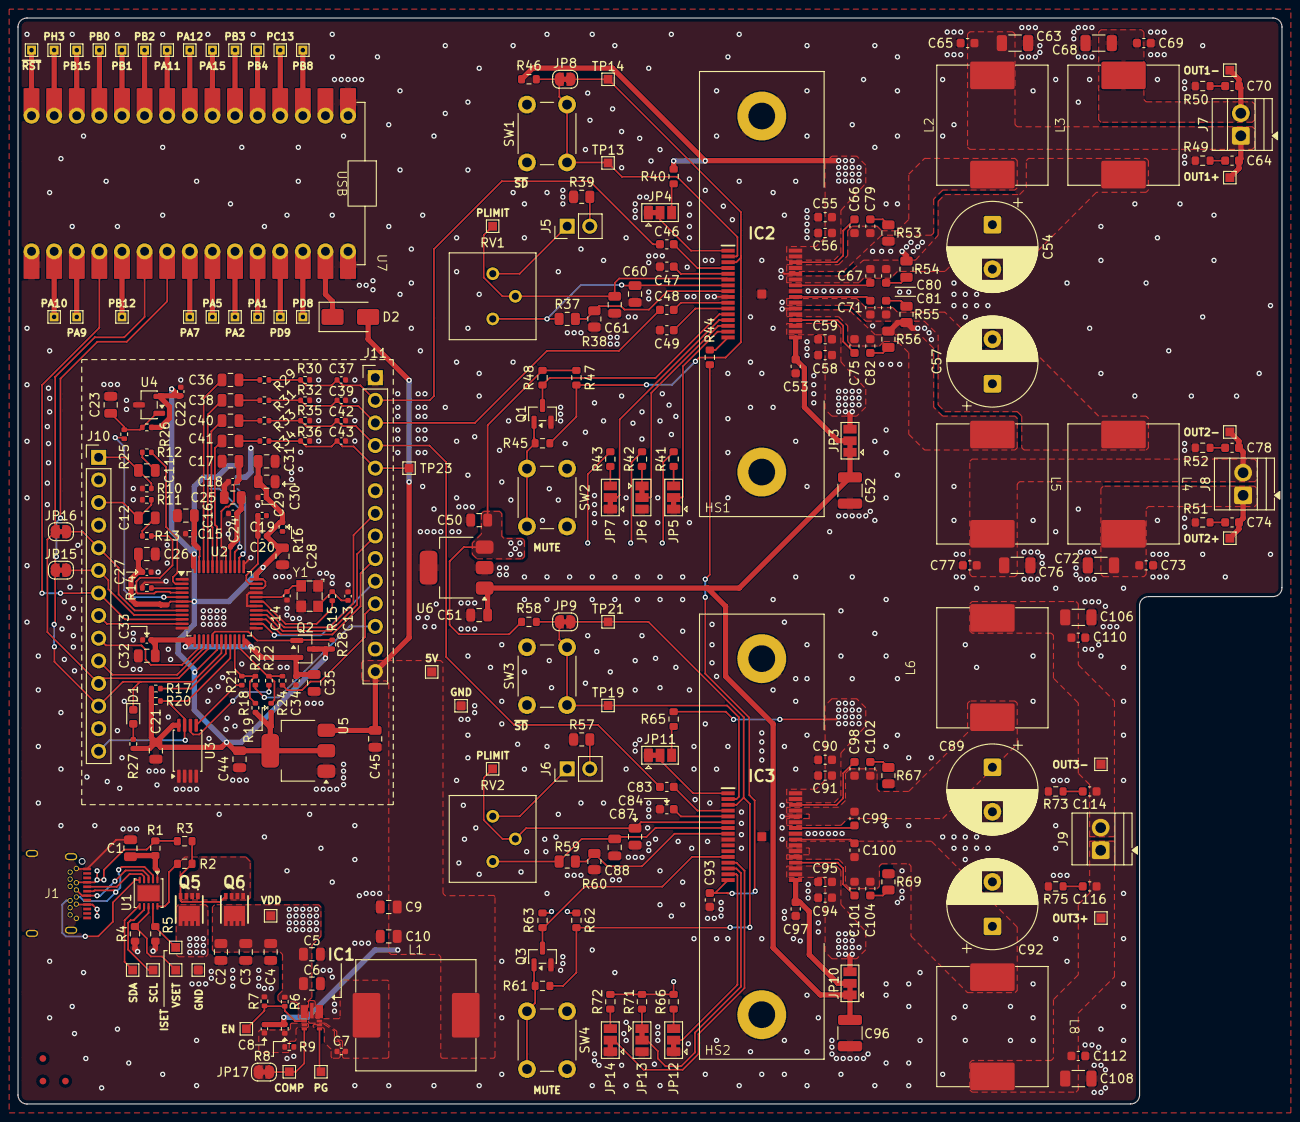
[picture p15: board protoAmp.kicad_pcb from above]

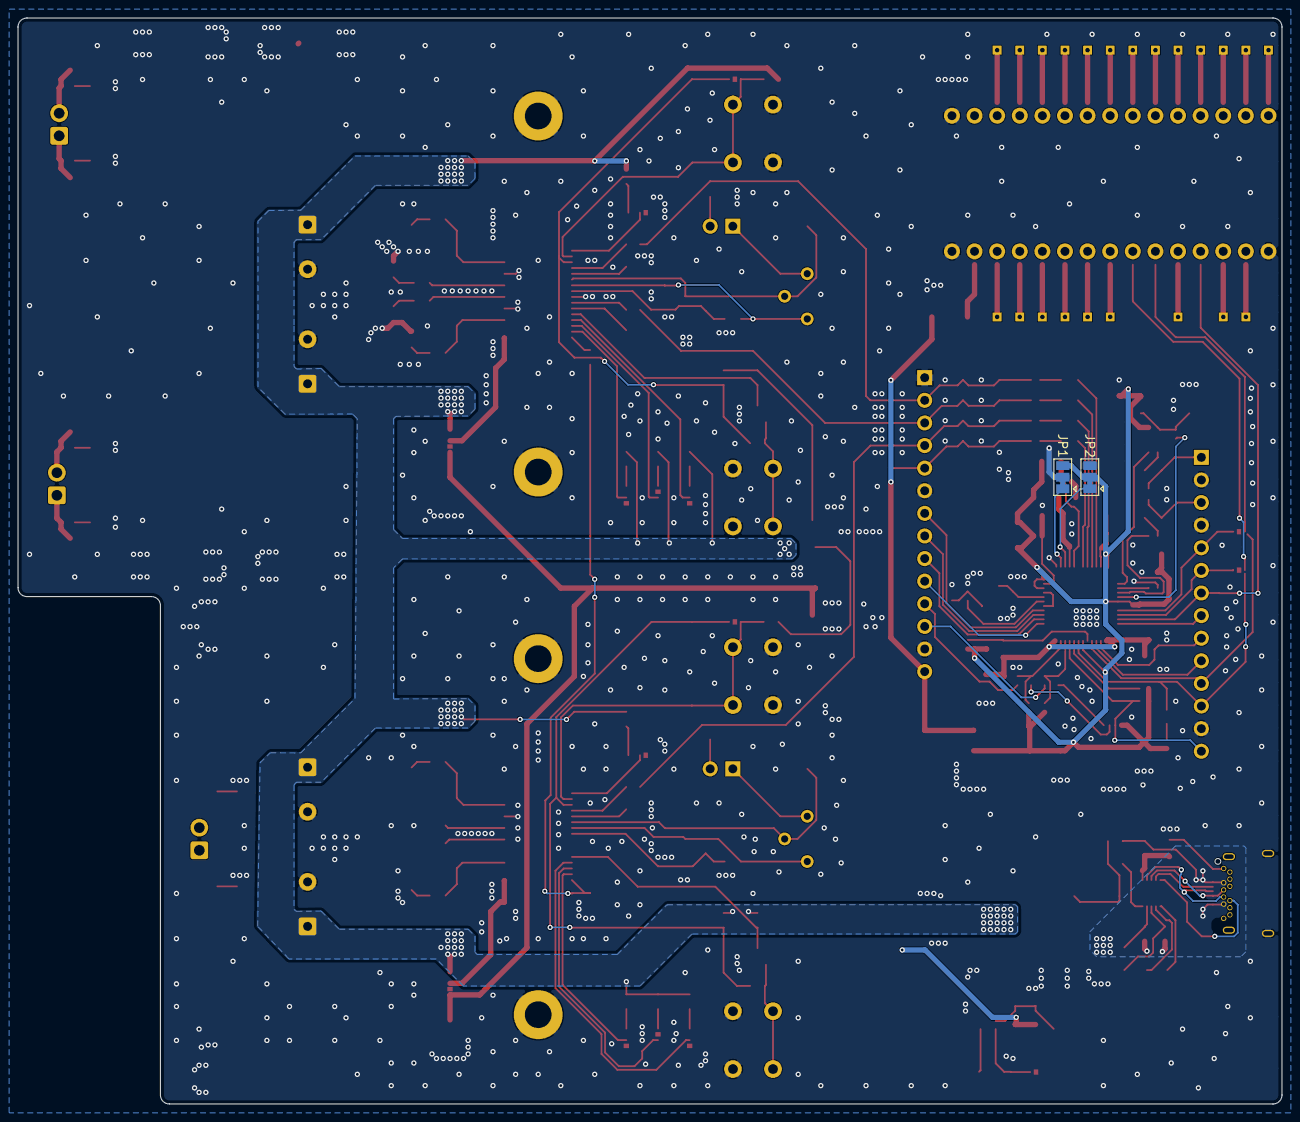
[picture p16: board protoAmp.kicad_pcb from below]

Board: 4 copper layers, 142.0 x 122.0 mm, 284 parts (2 on the bottom side), 177 nets.
